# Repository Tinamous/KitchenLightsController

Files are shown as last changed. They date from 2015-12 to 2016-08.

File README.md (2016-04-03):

# KitchenLightsController
IoT Particle Photon powered kitchen lights controller. Switch and dim LED and halogen lights.

Assembly
--------

Mount SMD components.

Solder on JP1, 12V DC power in.
For 2 & 3 min molex headers use sponge to keep connectors in place. Solder single pin, and then reflow that pushing the connector square to the board.
Solder JP35, JP47, JP34, JP48, JP49 - 3 pin molex connectors. Farnell: 9731156
Solder JP201, 202, 203, 301, 302, 303, 401, 402, 403. Optionally solder JP501 or 502. (or both). Fit only as many as you need. Farnell: 9731148

Solder JP43 (terminal block).

Fit C1 (330nF. Farnell: 1902922
Solder headers for Photon. eBay.
F1 Fuse folder. Farnell: 1453528
IC1 7805 or eBay switching version
C4 1000uF 16v. Farnell: 9693610
Connect JP37 if using onboard 5V supply for NeoPixels.
Fit X2 if using USB 5V switch.
Fuse 5A quick blow: Farnell: 1354578

Before powering up:
Check 12V rails for short circuit.
Check 5V rails for short.
Check 3v3 rails for short.

Power up using low current limit on bench PSU (ca. 50m-100A)
Check 5v rail and adjust reg as needed. Expect 3 LEDs to light (12v, 5V and ext. 5V). 14-20mA consumption.

V2.03 Changed:
Moved via under Photon to not mess with silk screen.
Moved OSH logo to near USB A Socket to give it more room and allow the 5V LED to be reverse mounted.
TODO:
Move 5V LED to be reverse mounted
Change 5V usb switched connector to be 0.1" molex not screw terminal.
Correct Channel 4 & Ext. 5V supply screw terminals to be the correct way around (double line on outside of the board).

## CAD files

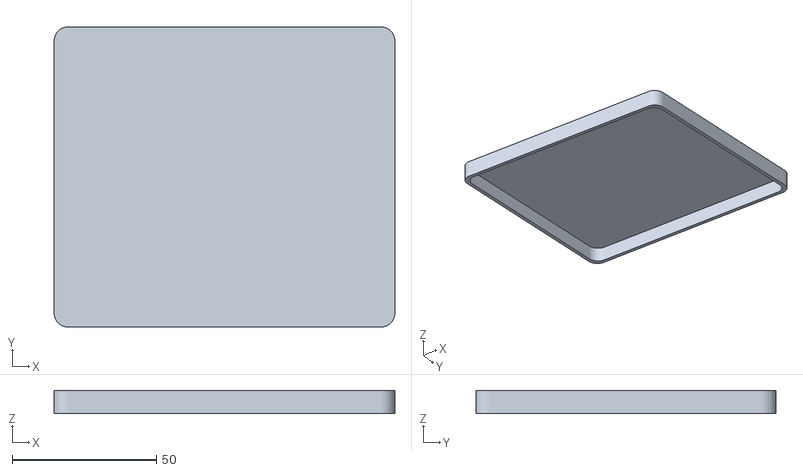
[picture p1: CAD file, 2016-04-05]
Case/LightControllerBoxLid.stl
118.0 x 103.9 x 8.00

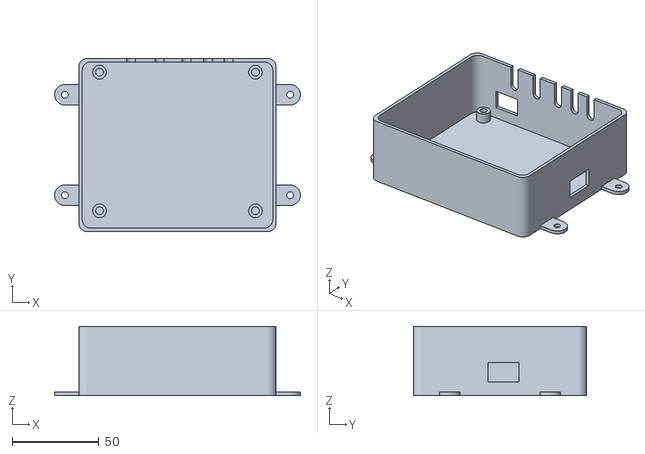
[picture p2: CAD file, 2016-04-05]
Case/LightControllerBox-NoSwitch.stl
142.0 x 99.9 x 40.0

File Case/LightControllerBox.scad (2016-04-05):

boxWidth = 114;
boxDepth = 100;
boxHeight = 40;
//boxHeight = 5;
standOffHeight = 8;
$fn = 20;

// Normal offset is center. Use this
// to push the box left/right/up/down
pcbXOffsetInBox = -0;
pcbYOffsetInBox = 2;

pcbWidth = 100;
pcbHeight = 90;
pcbMountOffset = 5; // m55 in from top/bottom for the PCB mounting hole

pcbOffsetX = ((boxWidth - pcbWidth) /2) + pcbXOffsetInBox; // 7.5mm
pcbOffsetY = ((boxDepth - pcbHeight) /2) + pcbYOffsetInBox;  // 15mm

switchDiameter = 17.5; 
switchX = (boxWidth/4) *3;
switchY = boxHeight - 15;

// Mounting. Tabs/Holes?
includeTabs = true;
includeHoles = false;
includeMountingPosts = false;

// Which part to build?
showBox = false;
showLid = true;
includeSwitchHole = false;

// Debugging
showPcb = false;
showSwitch = false;


// -----------------------------------------
// -----------------------------------------
module GenericBase(xDistance, yDistance, zHeight) {
	// roundedBox([xDistance, yDistance, zHeight], 2, true);

	// Create a rectangluar base to work from that
	// is xDistance by yDistance and zHeight height.

	// This is effectivly a cube with rounded corners

	// extend the base out by 3.5 from holes by using minkowski
	// which gives rounded corners to the board in the process
	// matching the Gadgeteer design
	
	$fn=30;
	radius = 5; //bezelSize;
	translate([radius,radius,0]) {
		minkowski()
		{
			// 3D Minkowski sum all dimensions will be the sum of the two object's dimensions
			cube([xDistance-(radius*2), yDistance-(radius*2), zHeight /2]);
			cylinder(r=radius,h=zHeight/2);
		}
	}
}

module OuterBox() {
    difference() {
        union() {
            GenericBase(boxWidth,boxDepth,boxHeight);
        }
        union() {
            translate([2,2,2]) {
                GenericBase(boxWidth - 4,boxDepth-4,boxHeight);
            }
            
            //translate([boxWidth /2,boxDepth/2,0]) {
            /*
            // Through hold
            translate([boxWidth /2,boxDepth-15,0]) {
                cylinder(d=15, h=3);
            }
            */
            
            // Drill out the mounting holes
            if (includeHoles) {
                MountingHoles();
            }
            
            if (includeSwitchHole) {
                SwitchHole();
            }
            
            cableExitHoles();
            
            usbConnectorHole();
            
            powerConnectorHole();
        }
    }
}

module cableExitHole(width) {
    #cube([width, 10,20]);
    translate([ (width/2), 10, 0]) {
        rotate([90,0,0]) {
            #cylinder(d=width, h=10);
        }
    }
}

module powerConnectorHole() {   
    
    translate([pcbOffsetX + 9.5, boxDepth-4,  standOffHeight+1]) {    
        #cube([16,7, 11]);
    }
}

// This may need supports.
module usbConnectorHole() {
    translate([boxWidth-4, pcbOffsetY + 36,  standOffHeight]) {    
        #cube([8,18, 8 + 3]);
    }
}

// Cut out holes in the wall for the light cables
// to exit.
module cableExitHoles() {
    
    translate([pcbOffsetX, boxDepth -4,  boxHeight-12]) {    
        // Channel 1
        translate([20.5, 0, 0]) {
            cableExitHole(5.2);
        }
        
        // Channel 2
        translate([37, 0, 0]) {
            cableExitHole(5.2);
        }
        
        // Channel 3
        translate([52.7, 0, 0]) {
            cableExitHole(5.2);
        }
        
        // Channel 4
        translate([65, 0, 0]) {
            cableExitHole(5.2);
        }
        
        // NeoPixels
        translate([76.7, 0, 0]) {
            cableExitHole(5.2);
        }
    }   
}

module PcbMounts() {
    
    // Mount holes @5,5 in corners of PCV        
    PcbMount(pcbOffsetX + pcbMountOffset, pcbOffsetY + pcbMountOffset);
    PcbMount(pcbOffsetX + pcbMountOffset, pcbOffsetY + pcbHeight - pcbMountOffset);
    PcbMount(pcbOffsetX + pcbWidth - pcbMountOffset, pcbOffsetY + pcbMountOffset);
    PcbMount(pcbOffsetX + pcbWidth - pcbMountOffset, pcbOffsetY + pcbHeight - pcbMountOffset);
}

module PcbMount(x,y) {
mountSize = 8;
mountHoleSize = 4.5;
    
    translate([x,y,0]) {
        // Outer pad + inner hole (Not all the way through!)
        difference() {
            union() {
                cylinder(d=mountSize, h=standOffHeight);
            }
            union() {
                translate([0,0,2]) {
                    #cylinder(d=mountHoleSize, h=standOffHeight-2);
                }
            }
        }
    }
}

module LidPosts() {
    LidPost(0,0);
    LidPost(boxWidth-(2*5),0);
    LidPost(0,boxDepth-(2*5));
    LidPost(boxWidth-(2*5),boxDepth-(2*5));
}

module LidPost(x,y) {
    mountSize = 7;
    mountHoleSize = 3; //M3 hole
    lidDepth = 0;

    translate([x + 5,y + 5,0]) {
        // Outer pad + inner hole (Not all the way through!)
        difference() {
            union() {
                cylinder(d=mountSize, h=boxHeight - lidDepth);
            }
            union() {
                // 10mm hole from top only
                translate([0,0,boxHeight - lidDepth - 10]) {
                    #cylinder(d=mountHoleSize, h=10);
                }
            }
        }
    }
}

module MountingHoles() {
    offsetFromCorner = 30;
    MountingHole(offsetFromCorner,offsetFromCorner);
    MountingHole(boxWidth-offsetFromCorner,offsetFromCorner);
    MountingHole(offsetFromCorner,boxDepth-offsetFromCorner);
    MountingHole(boxWidth-offsetFromCorner,boxDepth - offsetFromCorner);
}

module MountingHole(x,y) {
    translate([x,y,0]) {
        #cylinder(d=4, h=2);
    }
}

module MountingTabs() {
    
    tabOffset = 15;
    tabWidth = 12;
    tabLength = 8;
    
    MountingTab(0, tabOffset, tabWidth, tabLength);
    MountingTab(0, boxDepth - tabOffset - tabWidth, tabWidth, tabLength);
    
    translate([boxWidth,boxDepth,0]) {
        rotate([0,0,180]) {
            MountingTab(0,15, tabWidth, tabLength);
            MountingTab(0, boxDepth - tabOffset - tabWidth, tabWidth, tabLength);
        }
    }
}

module MountingTab(x,y, tabWidth, tabLength, tabThickness = 2) {
    
    translate([x - tabLength,y ,0]) {
        
        
        difference() {
            union() {
                cube([tabLength,tabWidth,tabThickness]);
                
                translate([0,(tabWidth/2) ,0]) {
                    cylinder(d=tabWidth, h=tabThickness);
                }
            }
            union() {
                // Hole for screw
                translate([0,(tabWidth/2) ,0]) {
                    cylinder(d=4, h=4);
                }
            }
        }
    }
}

module SwitchHole() {
        
    rotate([90,0,0]) {
        translate([switchX,switchY,-3]) {
            #cylinder(d=switchDiameter, h=5);
        }
    }
}
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

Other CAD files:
Case/LightControllerBox.stl

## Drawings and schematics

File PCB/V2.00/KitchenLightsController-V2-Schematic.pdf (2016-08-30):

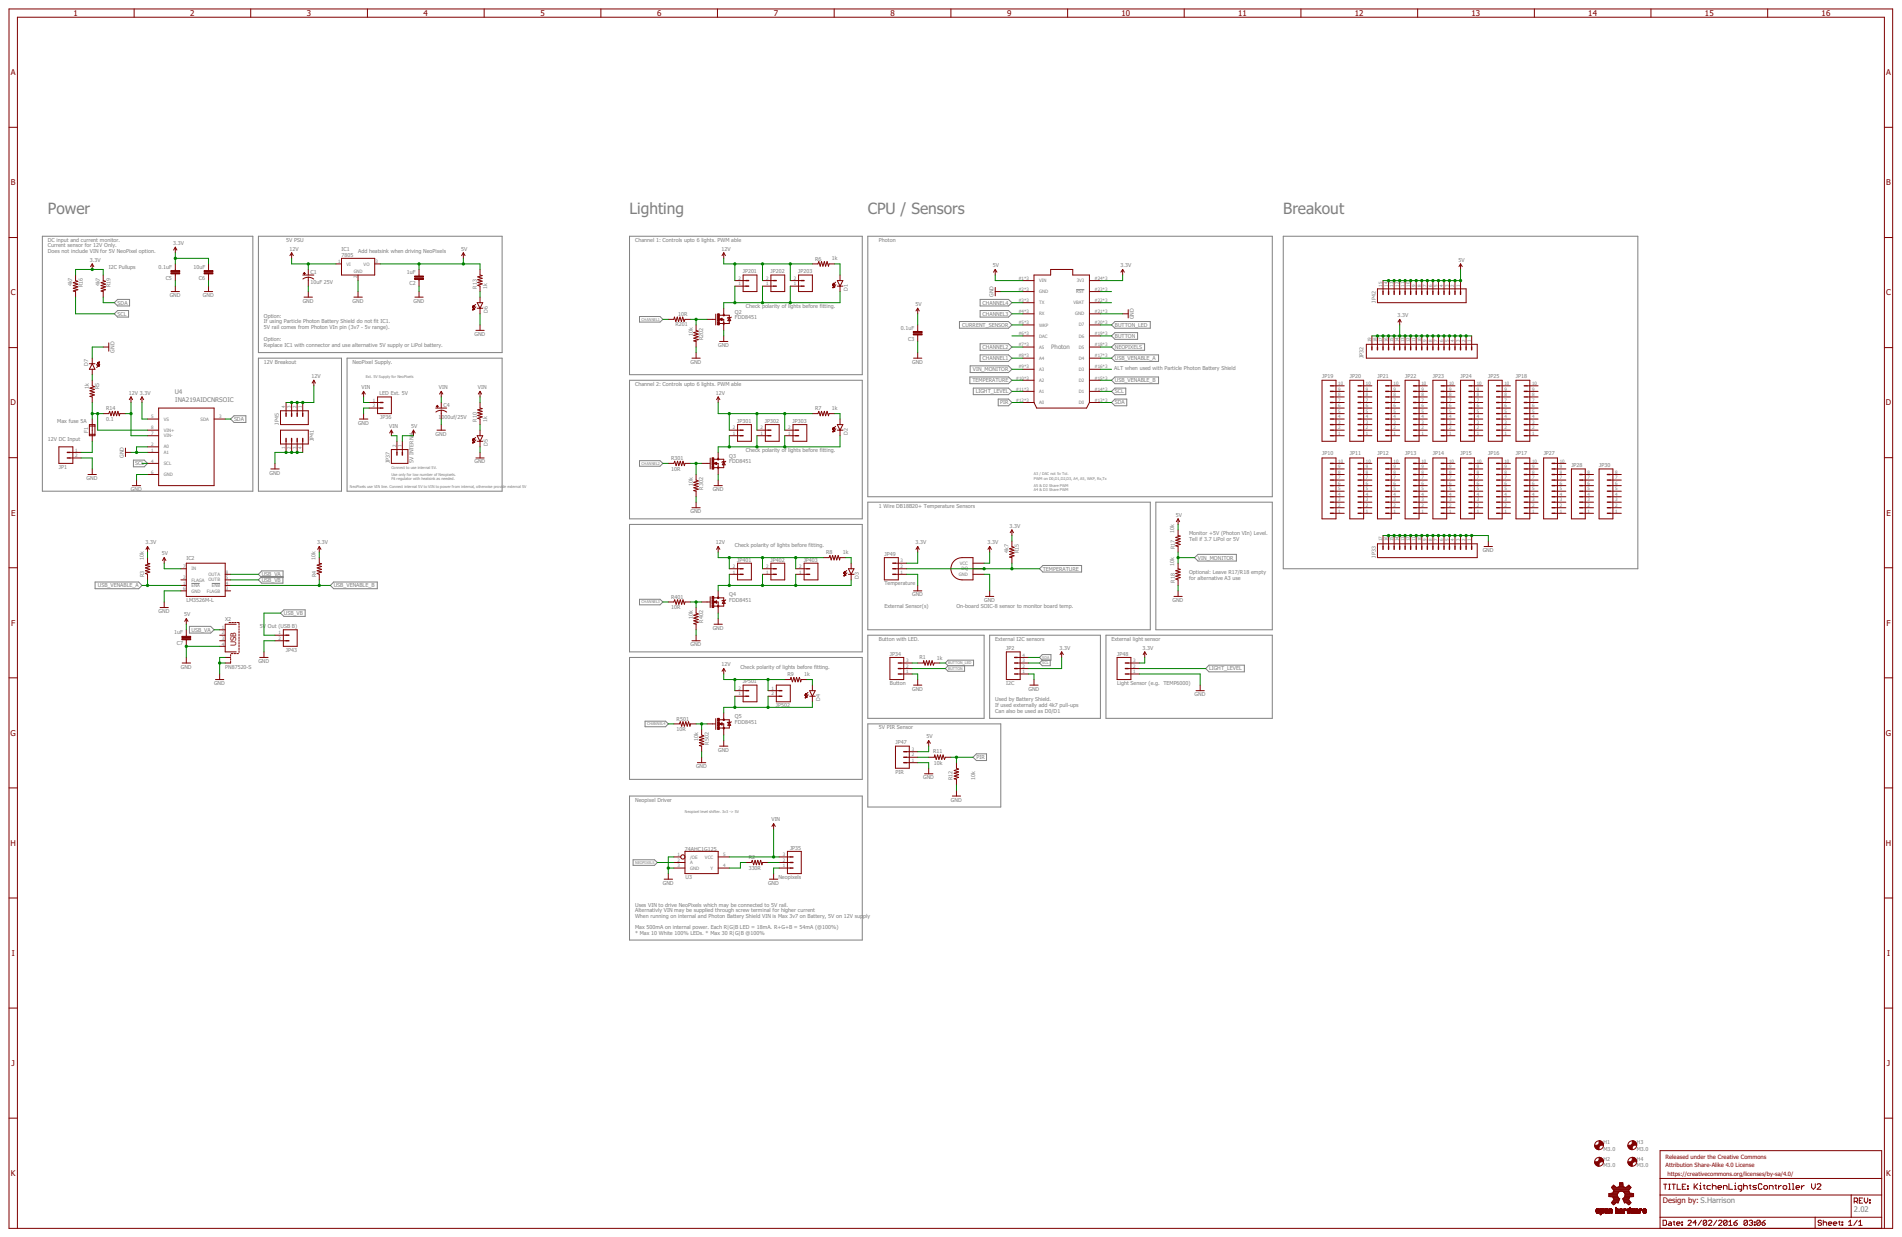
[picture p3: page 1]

DC input and current monitor.
Add heatsink when driving NeoPixels Current sensor for 12V Only. Does not include VIN for 5V NeoPixel option.

Channel 1: Controls upto 6 lights. PWM able

Option: If using Particle Photon Battery Shield do not fit IC1. 5V rail comes from Photon VIn pin (3v7 - 5v range). Option: Replace IC1 with connector and use alternative 5V supply or LiPol battery.

Check polarity of lights before fitting.
FDD8451

Ext. 5V Supply for NeoPixels

ALT when used with Particle Photon Battery Shield

Channel 2: Controls upto 6 lights. PWM able

12V DC Input Max fuse 5A

Connect to use internal 5V. Use only for low number of Neopixels. Fit regulator with heatsink as needed.

A3 / DAC not 5v Tol. PWM on D0,D1,D2,D3, A4, A5, WKP, Rx,Tx A5 & D2 Share PWM

NeoPixels use VIN line. Connect internal 5V to VIN to power from internal, otherwise provide external 5V

Monitor +5V (Photon VIn) Level. Tell if 3.7 LiPol or 5V Optional: Leave R17/R18 empty

Used by Battery Shield. If used externally add 4k7 pull-ups Can also be used as D0/D1

Uses VIN to drive NeoPixels which may be connected to 5V rail. Alternativly VIN may be supplied through screw terminal for higher current When running on internal and Photon Battery Shield VIN is Max 3v7 on Battery, 5V on 12V supply Max 500mA on internal power. Each R|G|B LED = 18mA. R+G+B = 54mA (@100%) * Max 10 White 100% LEDs. * Max 30 R|G|B @100%

Released under the Creative Commons Attribution Share-Alike 4.0 License https://creativecommons.org/licenses/by-sa/4.0/ Design by:

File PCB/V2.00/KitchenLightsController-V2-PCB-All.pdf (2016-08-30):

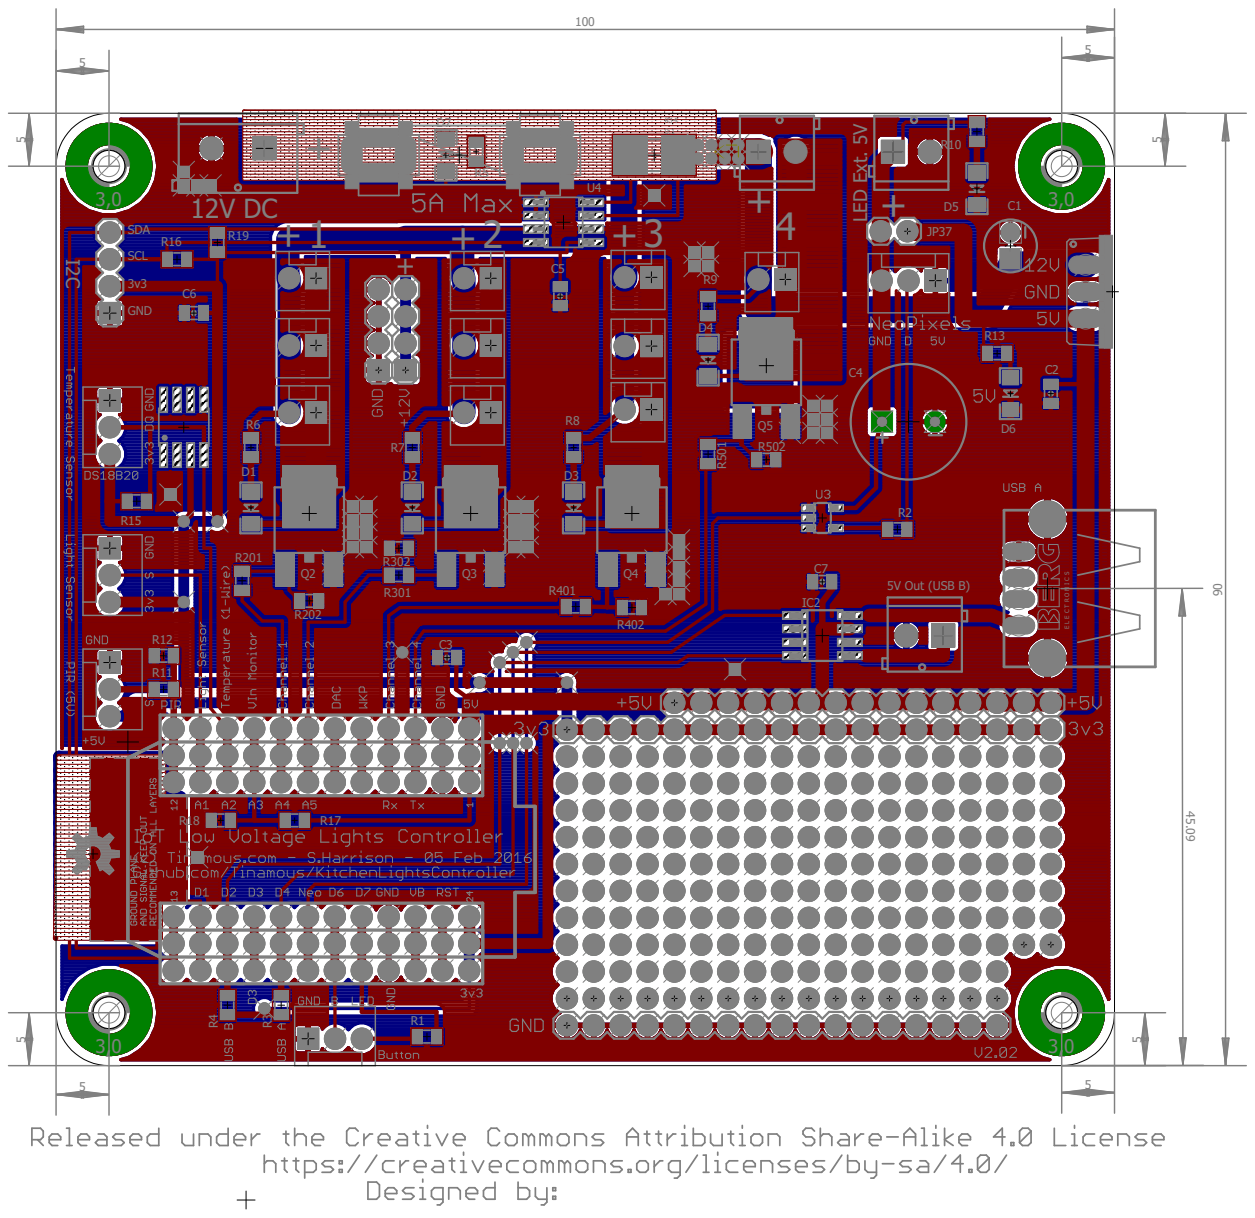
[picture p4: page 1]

GND

5V Out (USB B)

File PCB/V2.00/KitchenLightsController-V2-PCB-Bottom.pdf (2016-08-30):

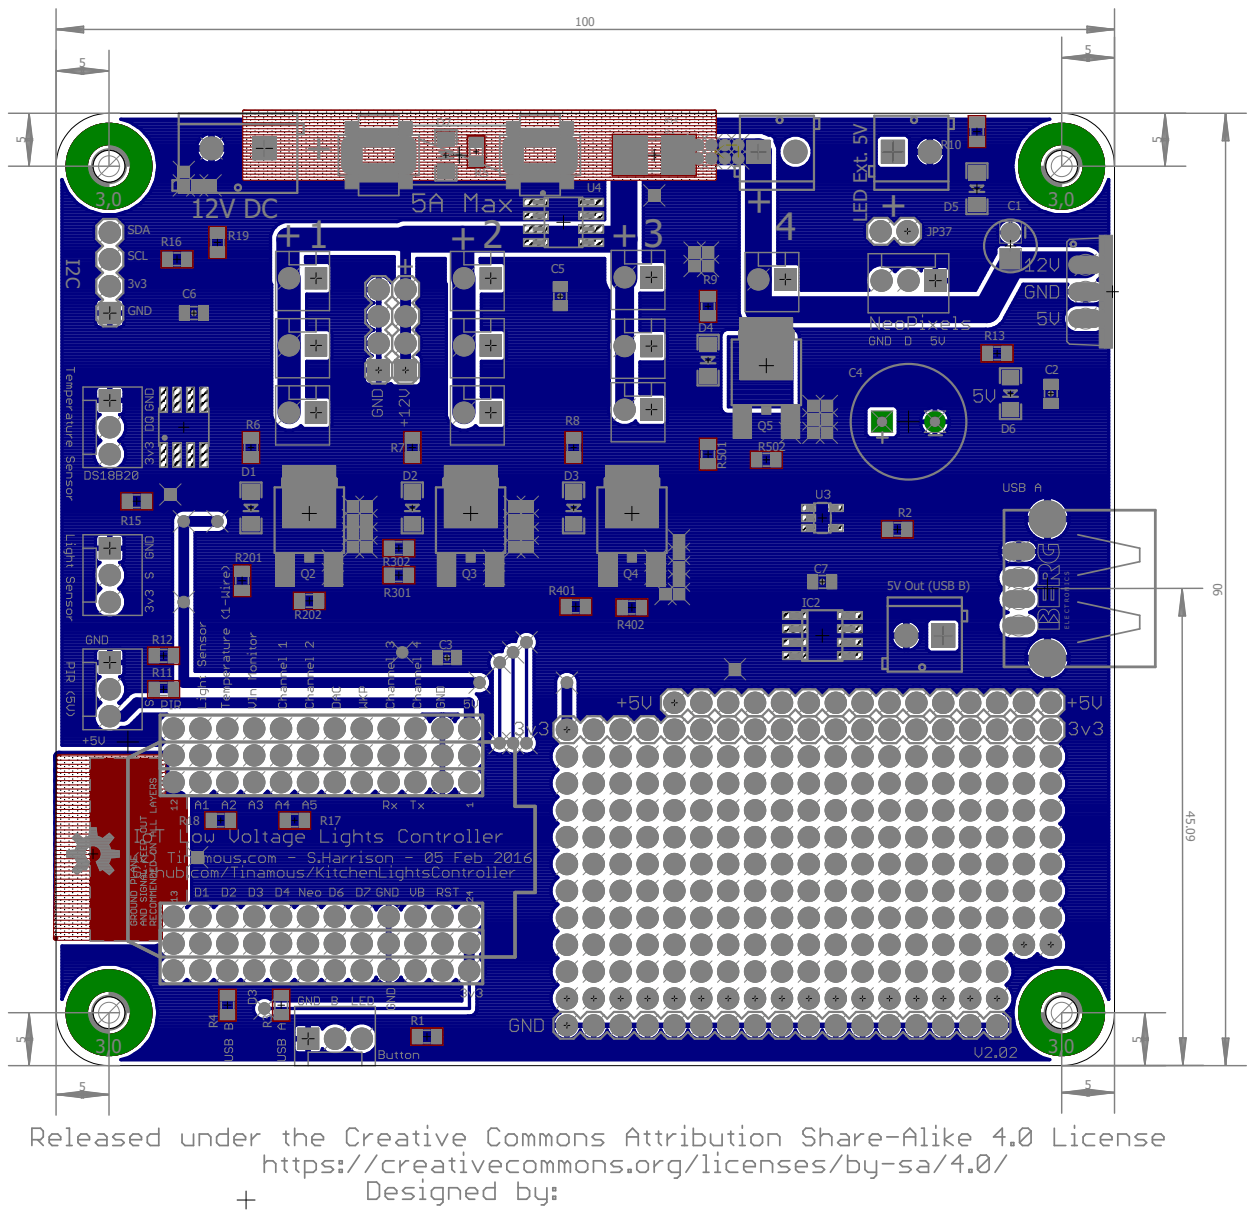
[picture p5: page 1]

5V Out (USB B)

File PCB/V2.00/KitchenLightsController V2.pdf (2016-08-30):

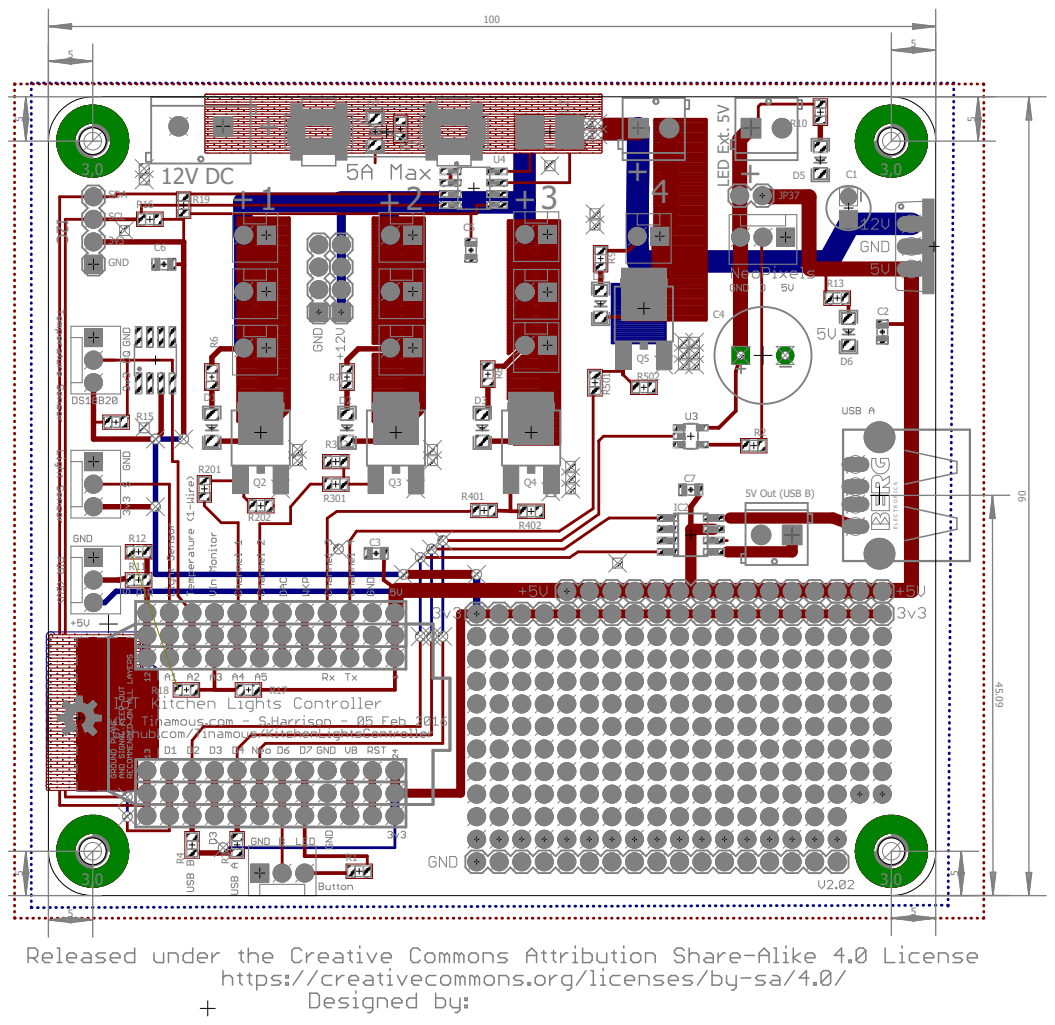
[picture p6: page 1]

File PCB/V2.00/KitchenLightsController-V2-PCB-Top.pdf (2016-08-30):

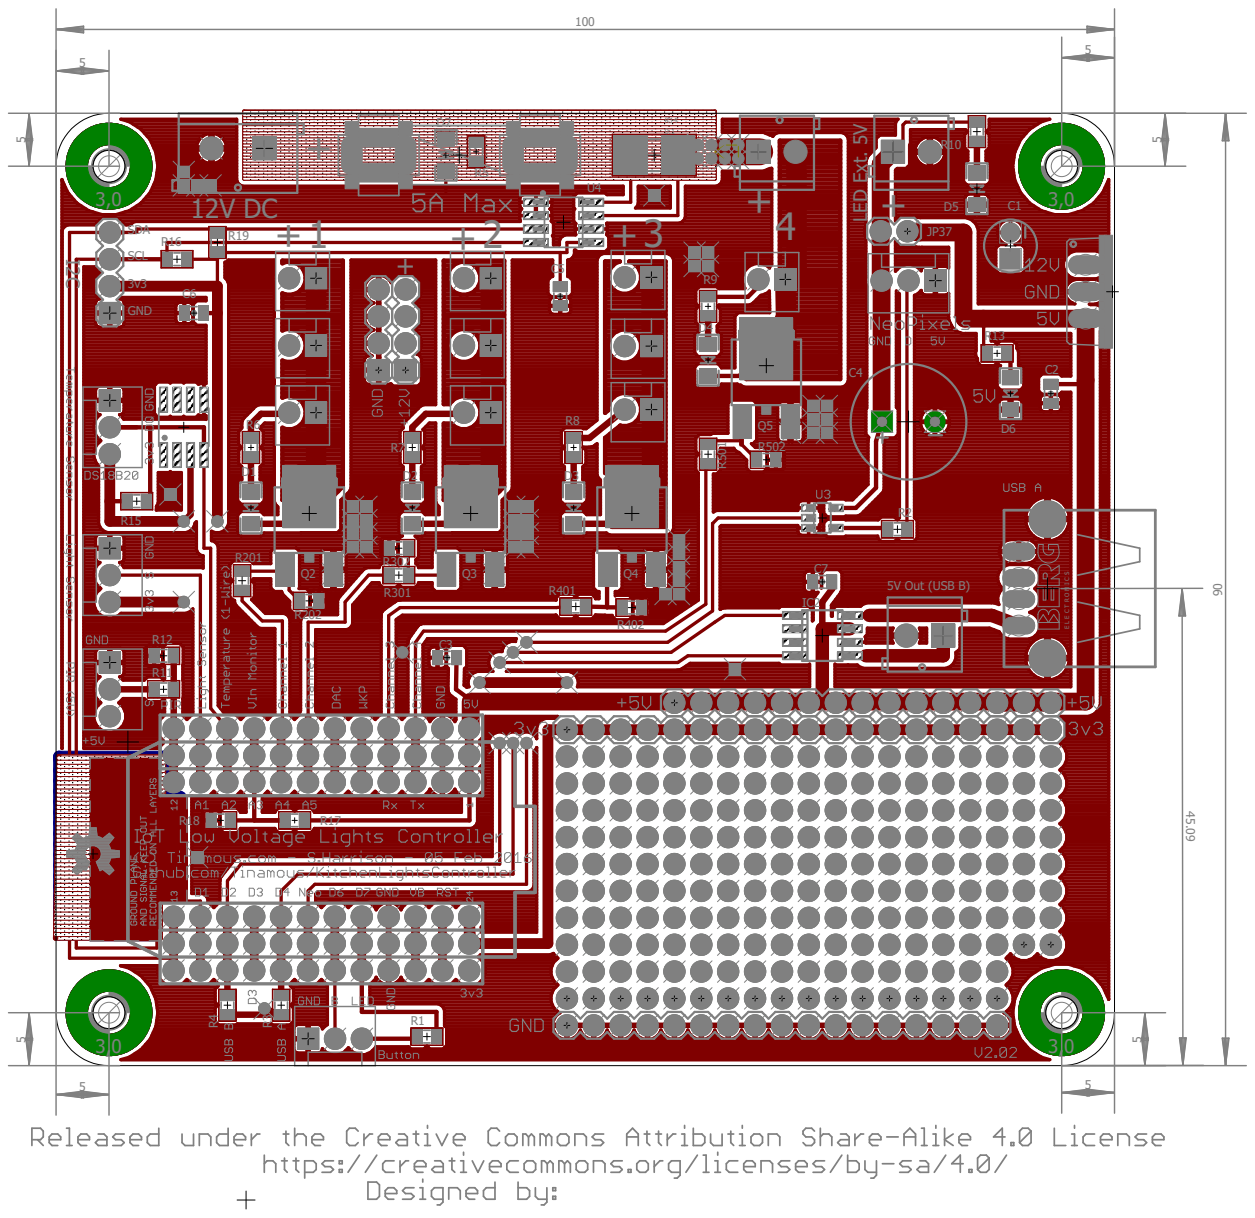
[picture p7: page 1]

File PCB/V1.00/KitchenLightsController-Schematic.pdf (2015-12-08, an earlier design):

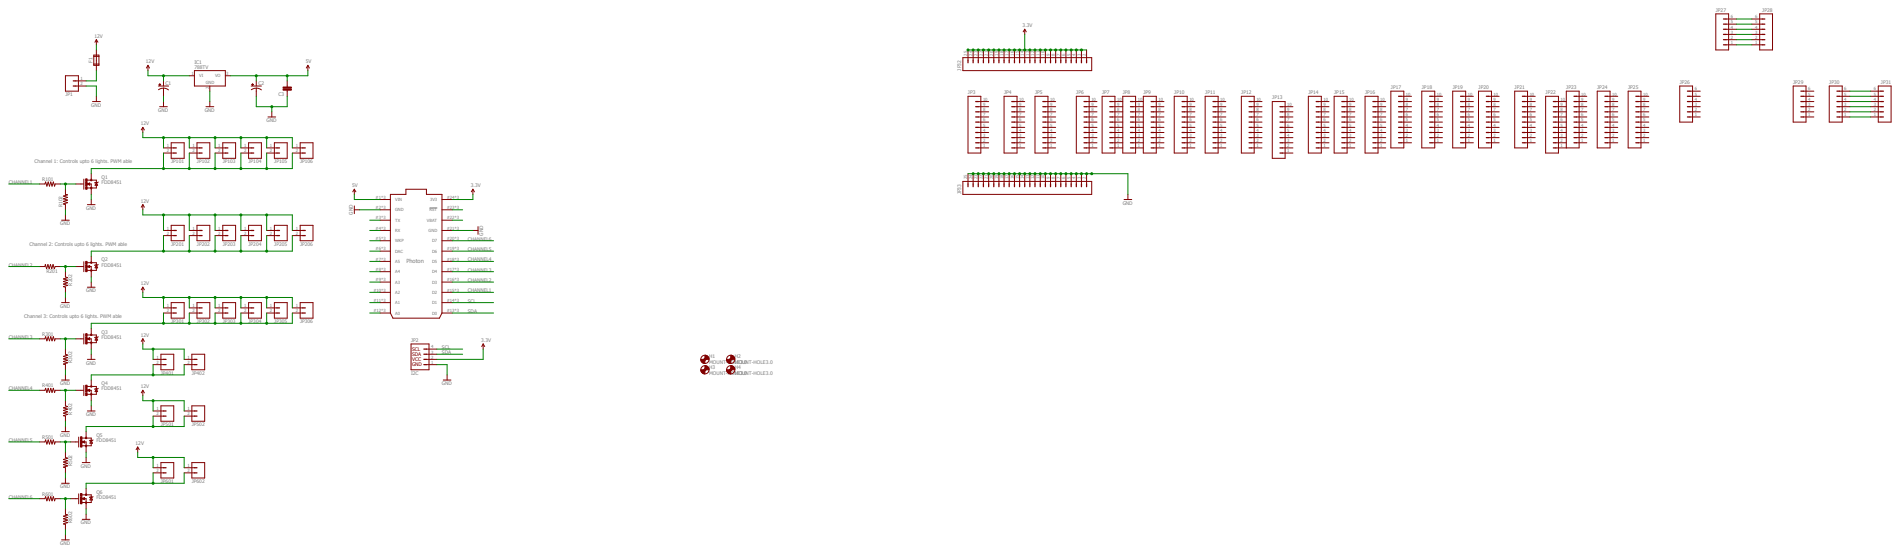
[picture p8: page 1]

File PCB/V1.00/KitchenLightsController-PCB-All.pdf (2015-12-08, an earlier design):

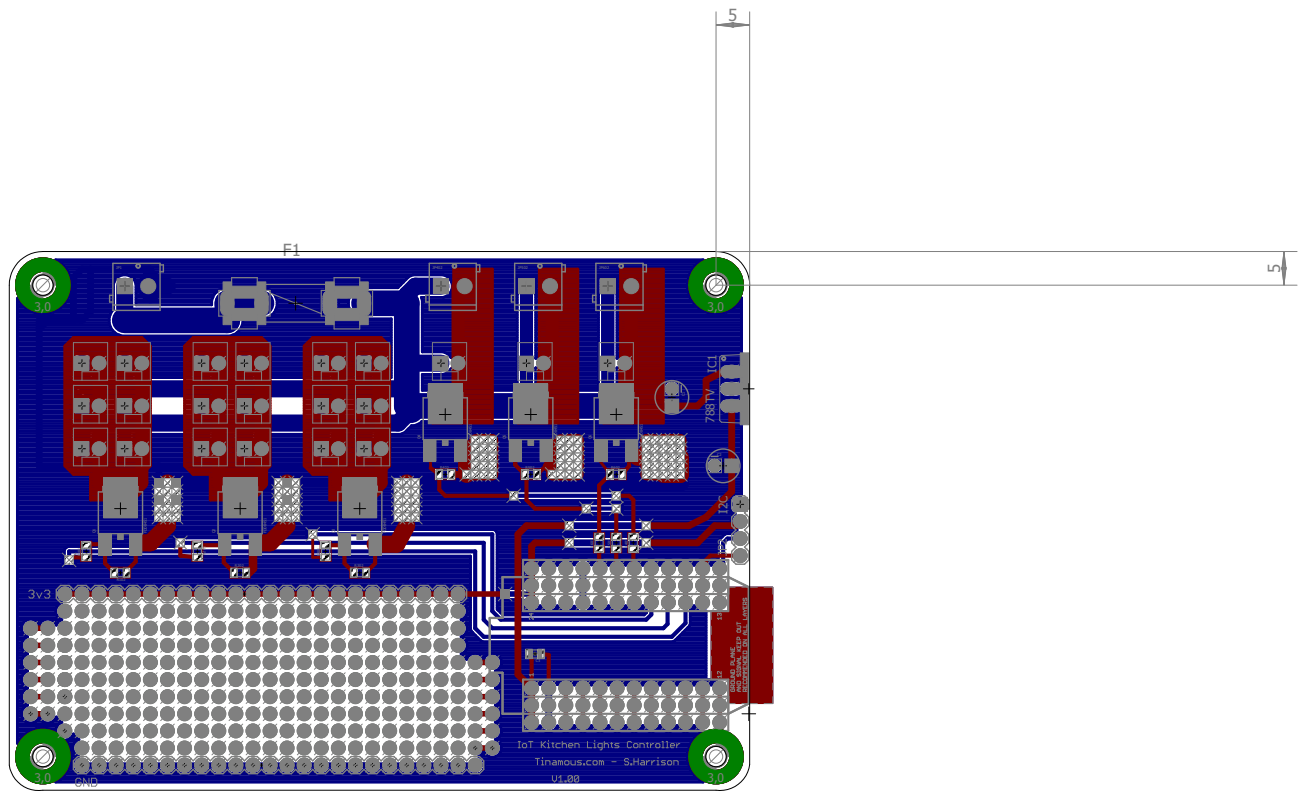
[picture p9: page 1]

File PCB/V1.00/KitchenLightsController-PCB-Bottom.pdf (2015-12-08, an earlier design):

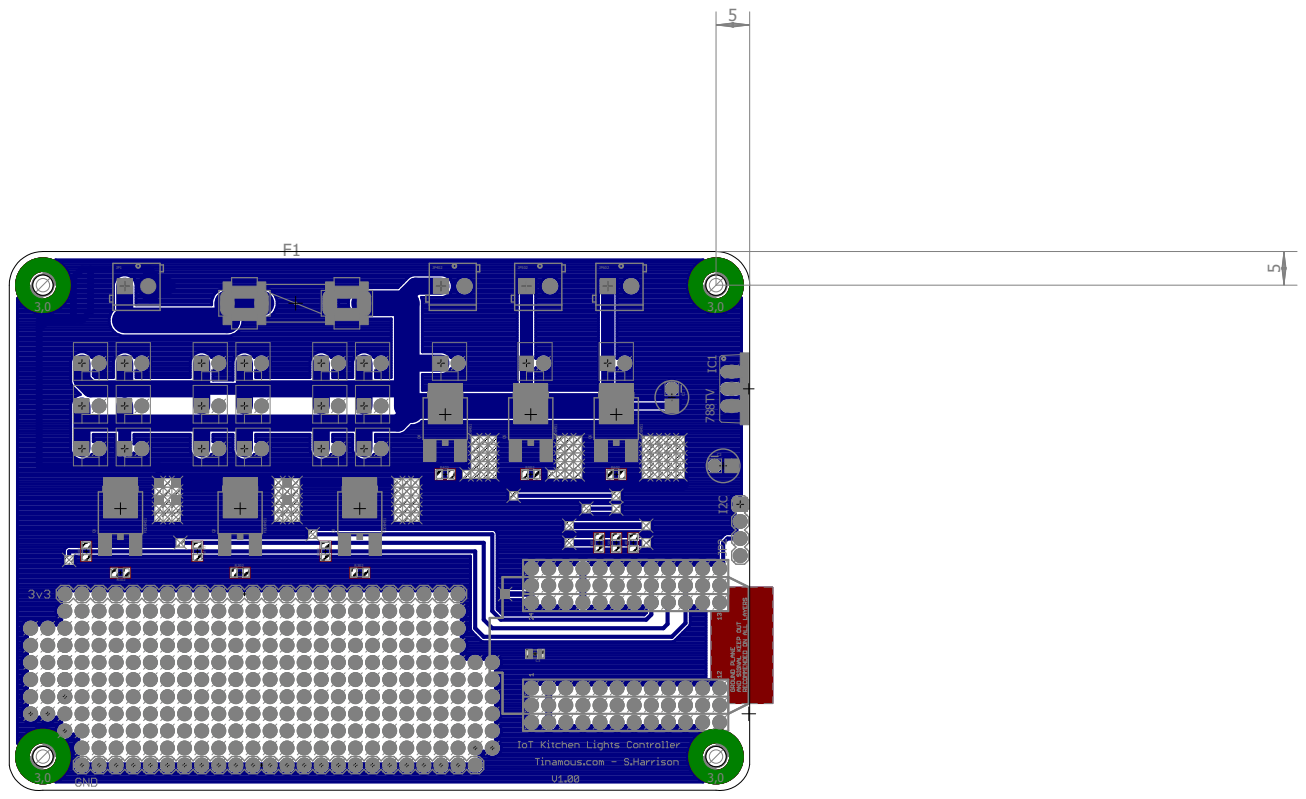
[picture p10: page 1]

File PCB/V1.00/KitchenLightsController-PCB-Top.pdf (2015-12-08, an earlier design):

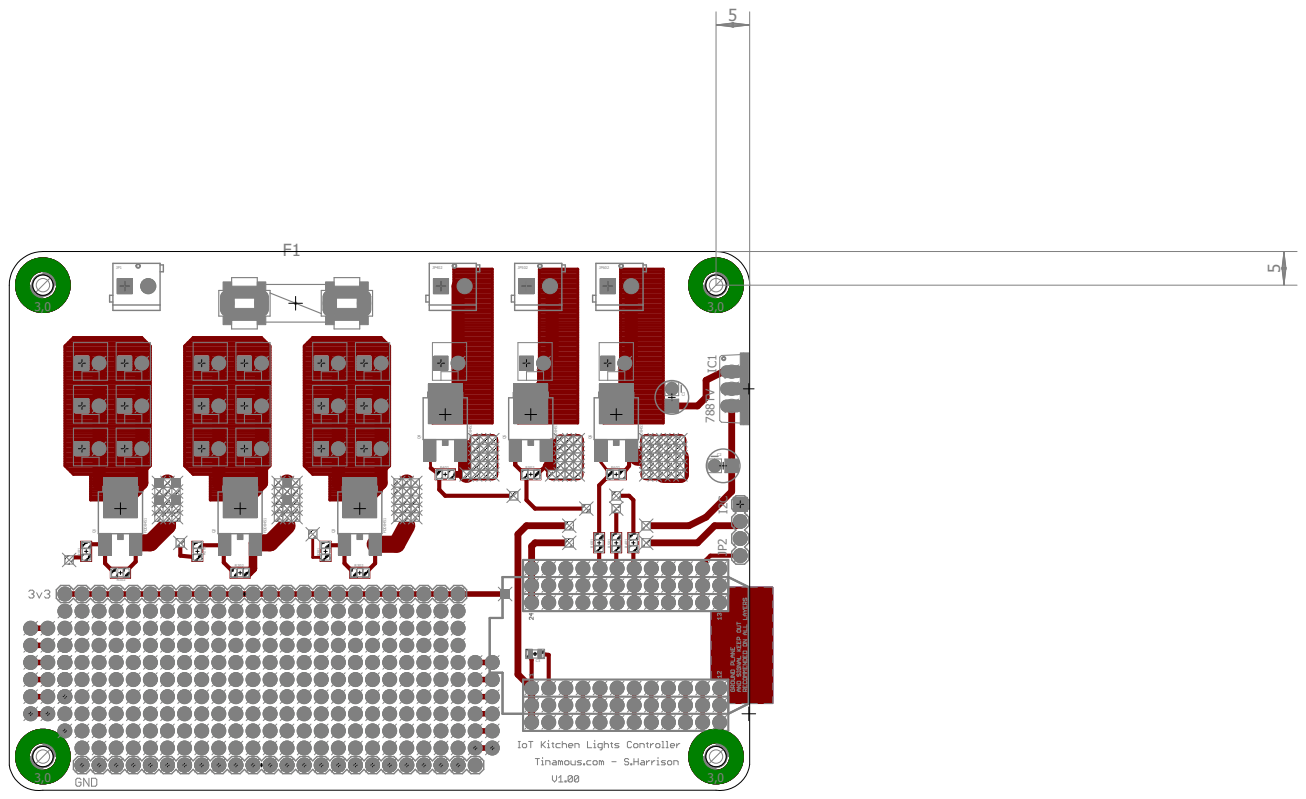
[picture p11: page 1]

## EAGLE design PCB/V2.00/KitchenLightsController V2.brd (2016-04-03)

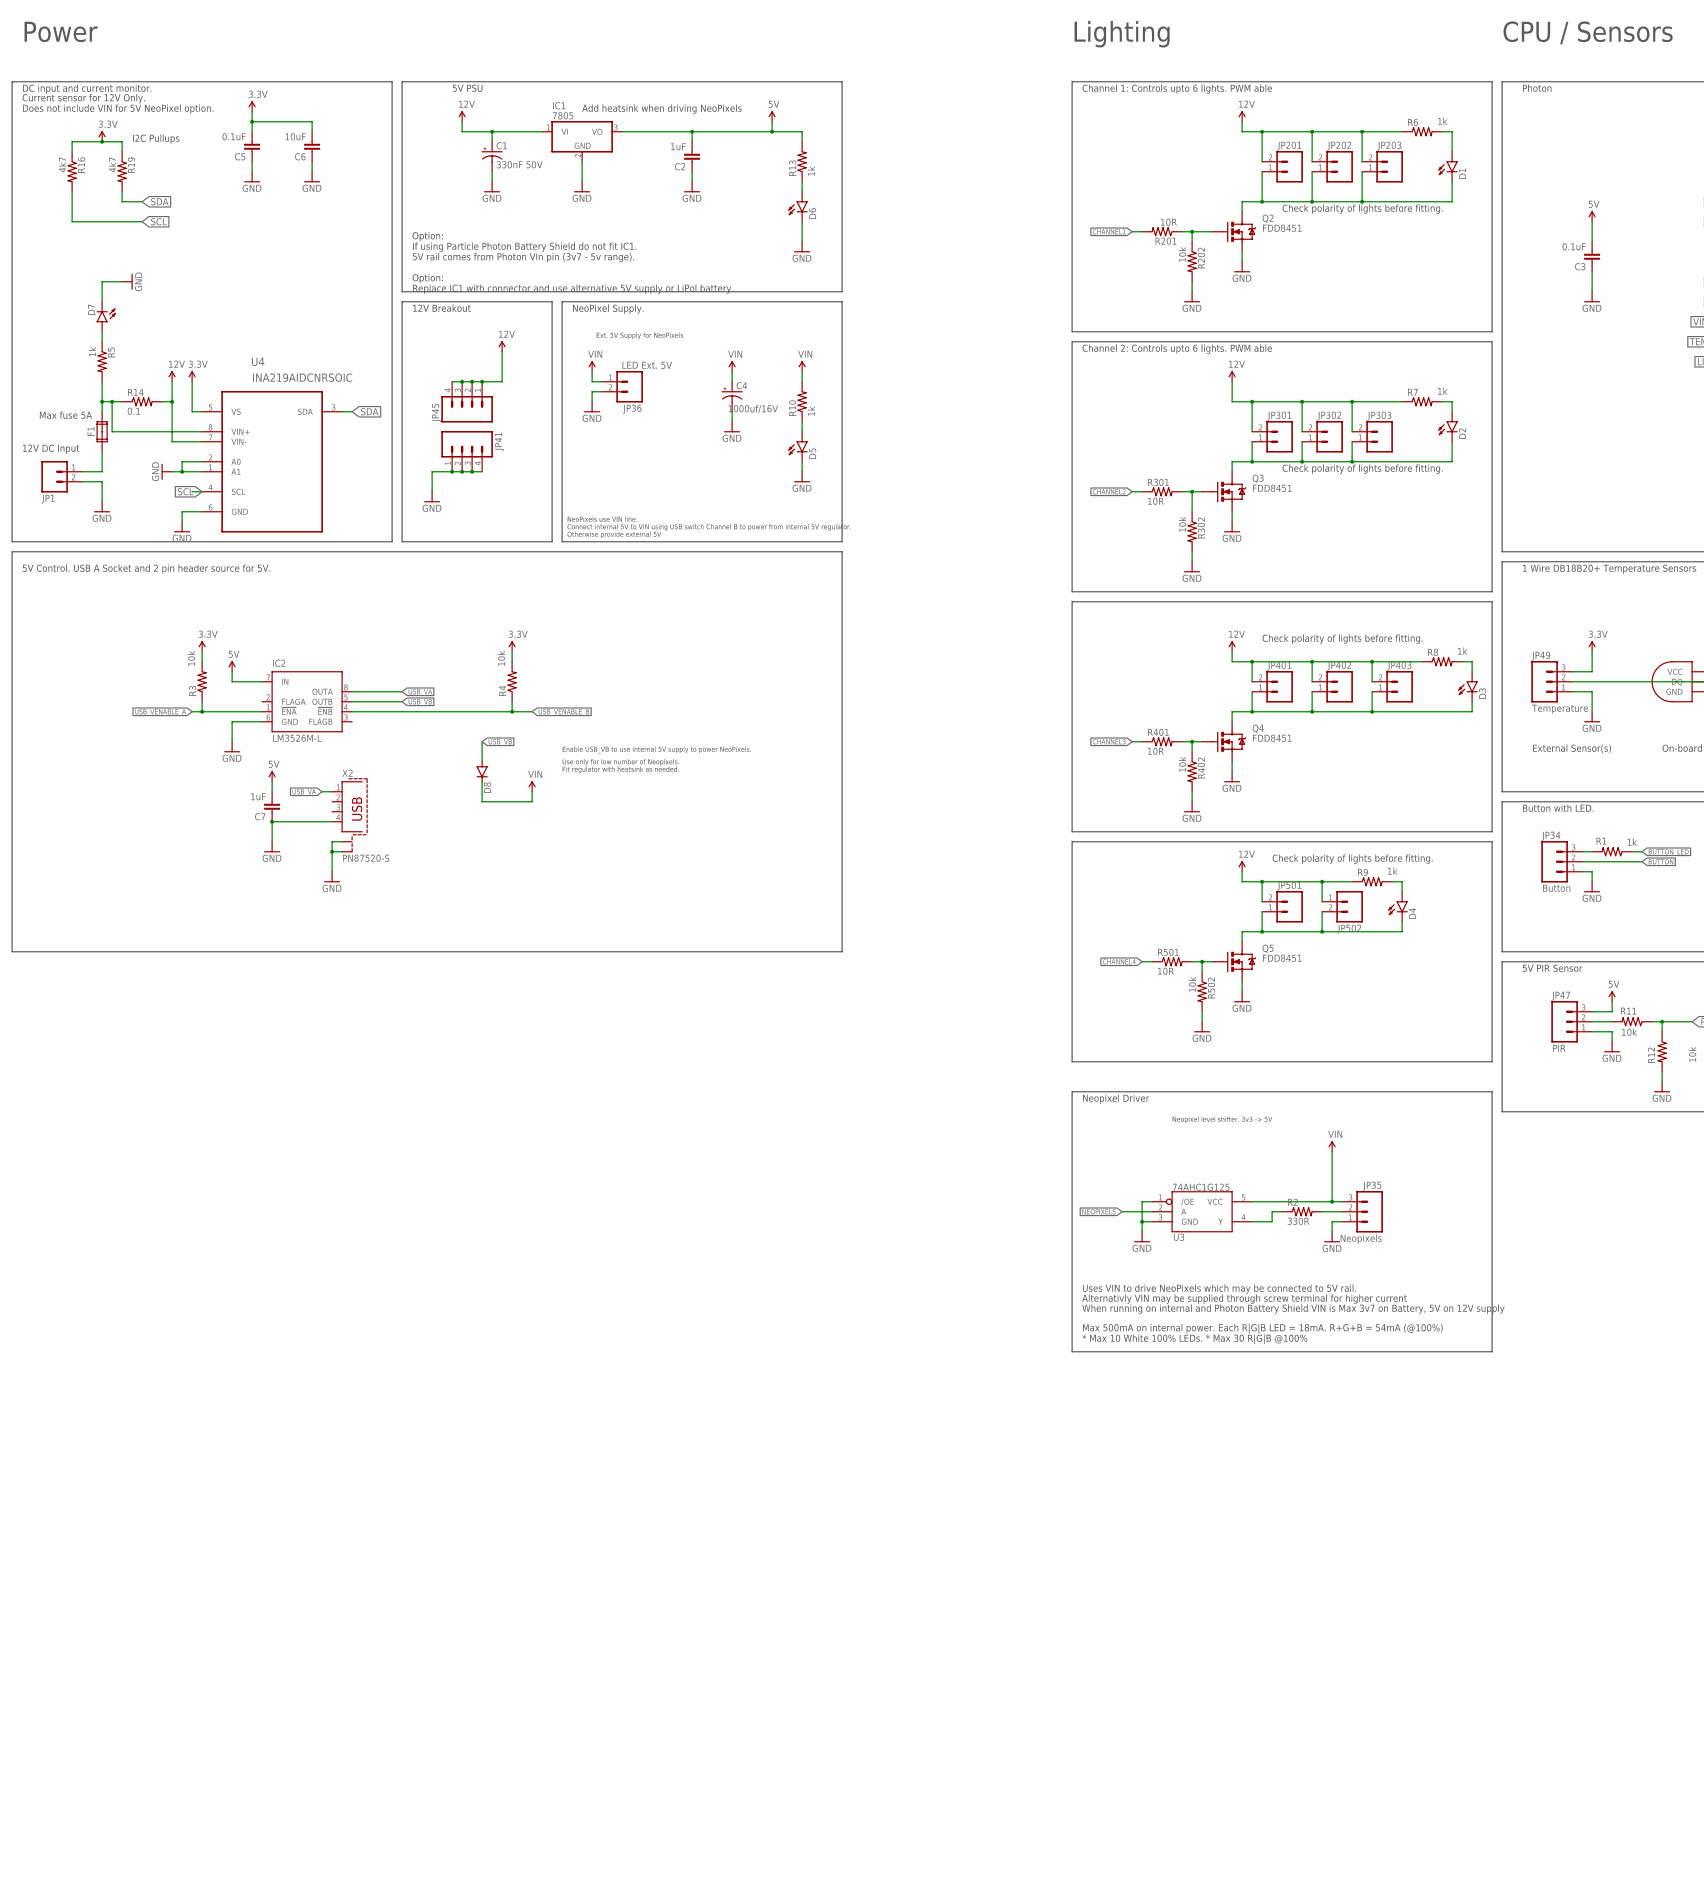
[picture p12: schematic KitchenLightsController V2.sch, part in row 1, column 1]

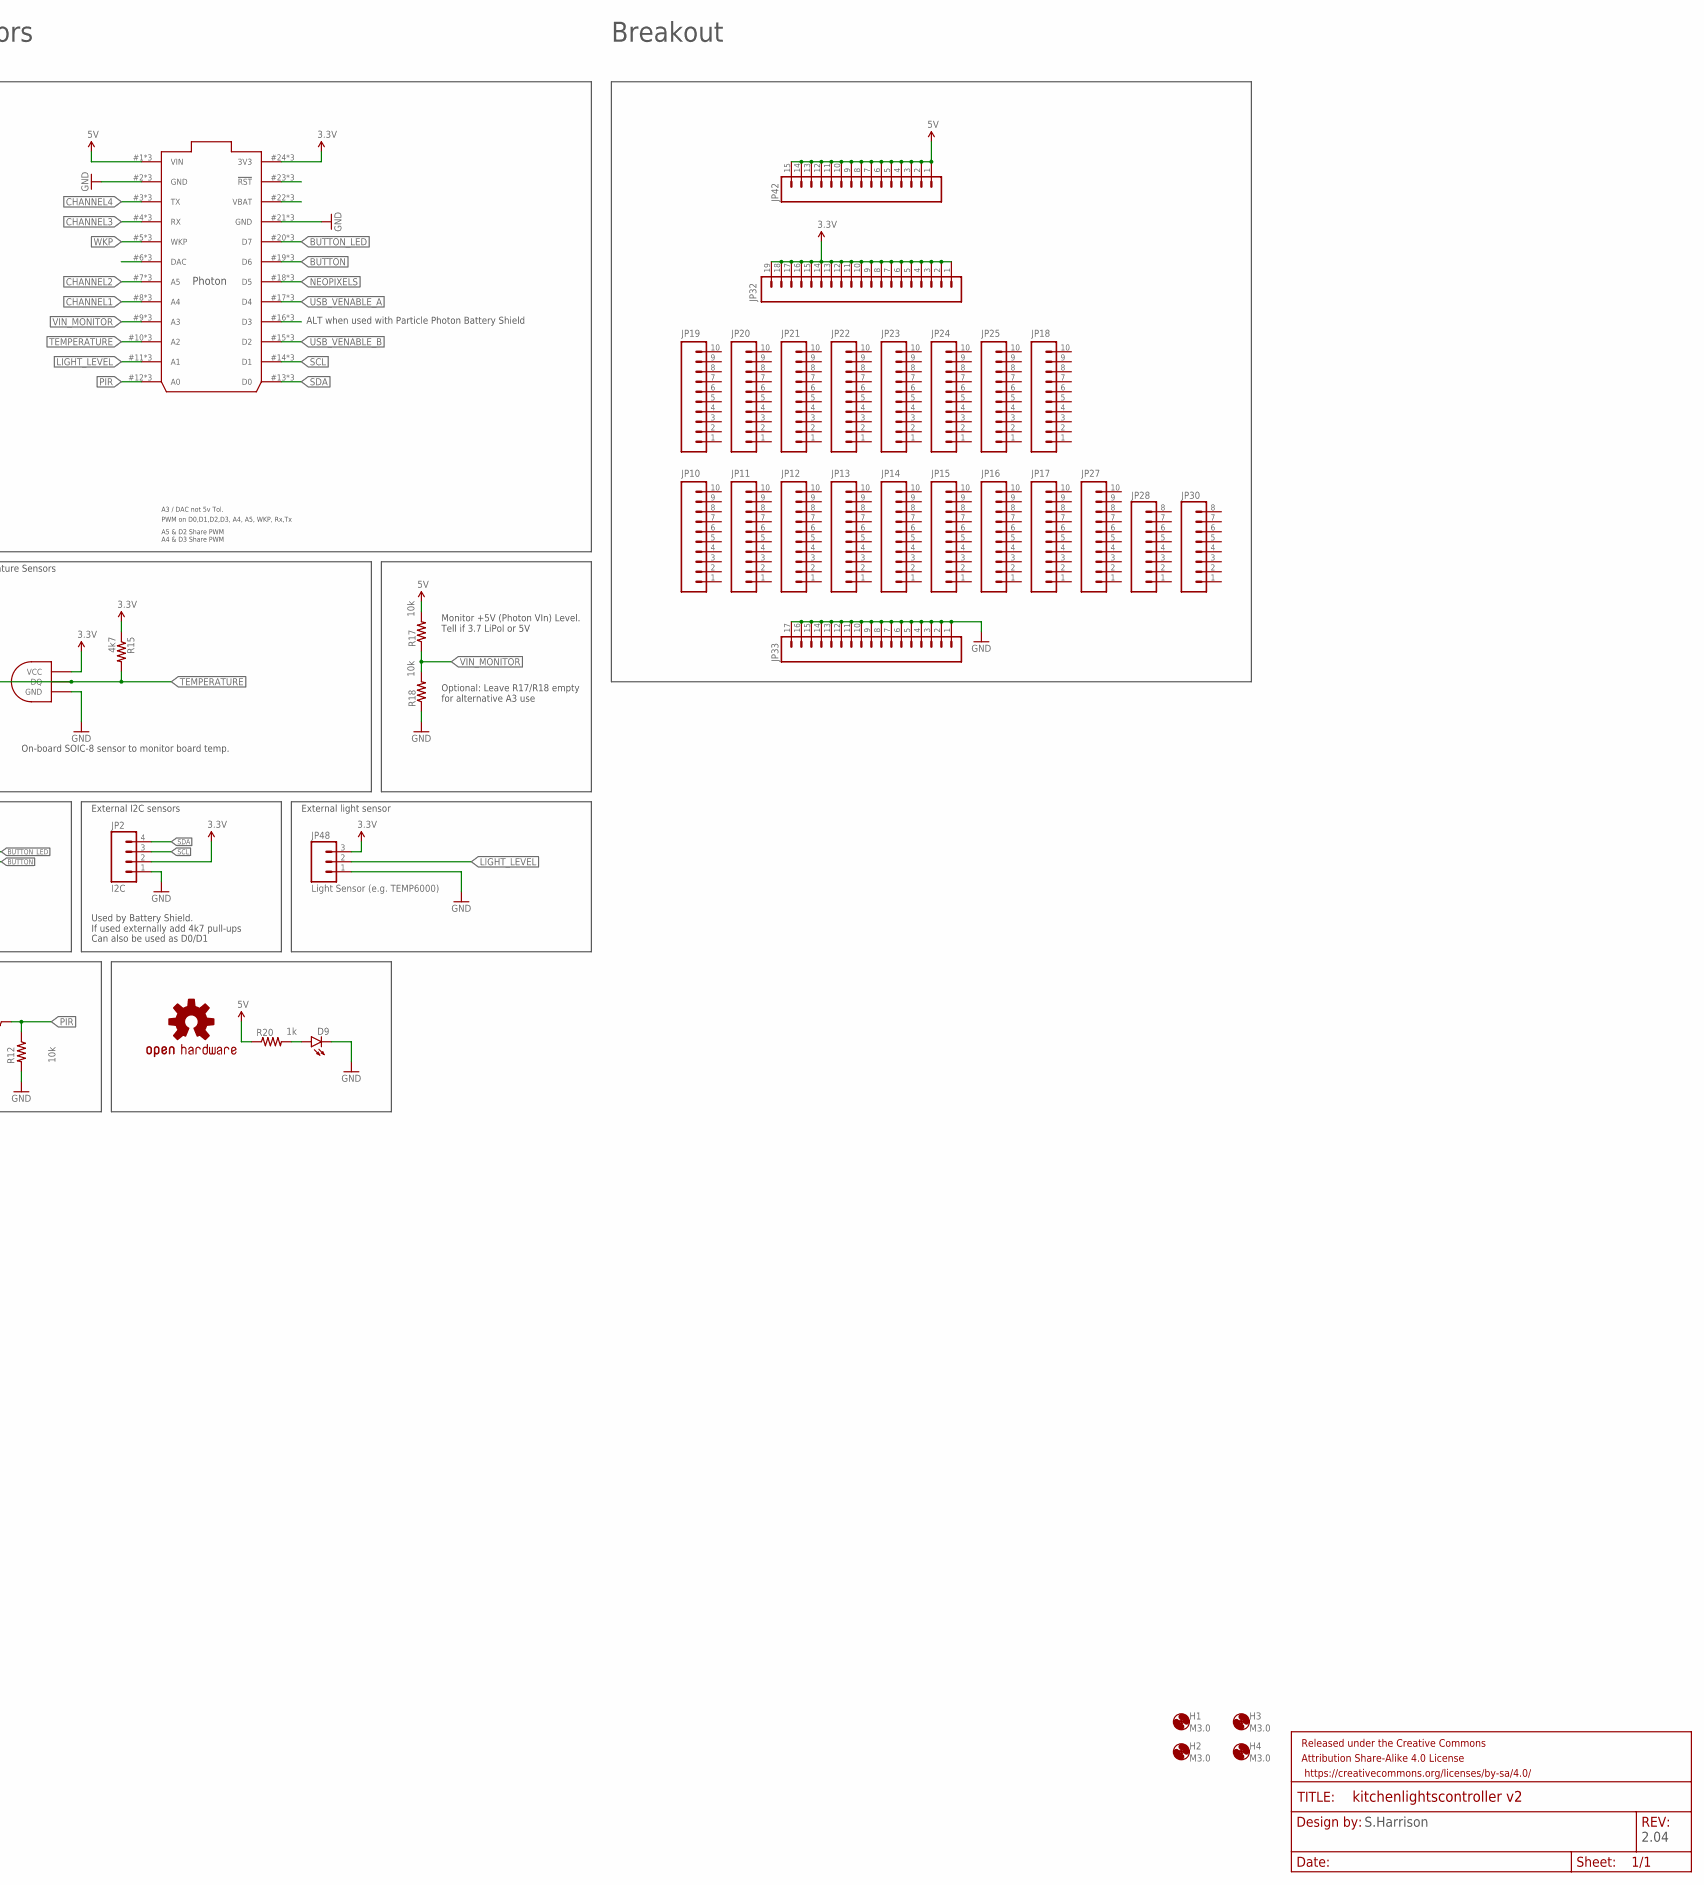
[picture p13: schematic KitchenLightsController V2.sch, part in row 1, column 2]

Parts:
C1: 330nF 50V; CPOL-RADIAL-10UF-25V; FARNELL 1902922
C2, C7: 1uF; 0805-CAP
C3, C5: 0.1uF; 0805-CAP
C4: 1000uf/16V; CPOL-RADIAL-1000UF-25V-KIT; FARNELL 9693610
C6: 10uF; 0805-CAP
D1, D2, D3, D4, D5, D6, D7: GREEN; LED-1206
D8: DIODESMA-KIT; SMA-DIODE-KIT
D9: LED1206-BOTTOM; LED-1206-BOTTOM
F1: FUSE2P; FUSE1; FARNELL 1453528
FRAME1: FRAME-LETTER; CREATIVE_COMMONS
H1, H2, H3, H4: M3.0; 3,0
IC1: 7805; TO220V
IC2: LM3526M-L; SO08
JP1: M025MM; SCREWTERMINAL-5MM-2; FARNELL 2008197
JP2: I2C; 1X04
JP10, JP11, JP12, JP13, JP14, JP15, JP16, JP17, JP18, JP19, JP20, JP21, JP22, JP23, JP24, JP25, JP27: M10NO_SILK_PTH_FEMALE; 1X10_NO_SILK
JP28, JP30: M08NO_SILK_FEMALE_PTH; 1X08_NO_SILK
JP32: M191X19; 1X19
JP33: M17; 1X17
JP34: Button; MOLEX-1X3; FARNELL 9731156
JP35: Neopixels; MOLEX-1X3; FARNELL 9731156
JP36: LED Ext. 5V; SCREWTERMINAL-3.5MM-2
JP41, JP45: M04PTH; 1X04
JP42: M15; 1X15
JP47: PIR; MOLEX-1X3; FARNELL 9731156
JP48: Light Sensor (e.g. TEMP6000); MOLEX-1X3; FARNELL 9731156
JP49: Temperature; MOLEX-1X3; FARNELL 9731156
JP201, JP202, JP203, JP301, JP302, JP303, JP401, JP402, JP403, JP501: M02POLAR; MOLEX-1X2
JP502: M023.5MM; SCREWTERMINAL-3.5MM-2
LOGO1: OSHW-LOGOM; OSHW-LOGO-M
Q2, Q3, Q4, Q5: FDD8451; DPAK
R1, R5, R6, R7, R8, R9, R10, R13, R20: 1k; 0805
R2: 330R; 0805
R3, R4, R11, R12, R17, R18, R202, R302, R402, R502: 10k; 0805
R14: 0.1; 2512; FARNELL 1435947
R15, R16, R19: 4k7; 0805
R201, R301, R401, R501: 10R; 0805
U1: PHOTON_WITH_STACKABLE_HEADERS; PHOTON_STACKABLE
U2: DS1820SOIC; DS18B20_SOIC
U3: 74AHC1G125; SOT23-5
U4: INA219AIDCNRSOIC; SO08
X2: PN87520-S

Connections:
3.3V: C5.2, C6.2, JP2.2, JP32.1, JP32.2, JP32.3, JP32.4, JP32.5, JP32.6, JP32.7, JP32.8, JP32.9, JP32.10, JP32.11, JP32.12, JP32.13, JP32.14, JP32.15, JP32.16, JP32.17, JP32.18, JP32.19, JP48.3, JP49.3, R3.2, R4.2, R15.1, R16.1, R19.1, U1.24 (3V3), U1.#24 (3V3), U1.@24 (3V3), U2.VCC, U4.5 (VS)
5V: C2.2, C3.2, C7.2, IC1.3 (VO), IC2.7 (IN), JP42.1, JP42.2, JP42.3, JP42.4, JP42.5, JP42.6, JP42.7, JP42.8, JP42.9, JP42.10, JP42.11, JP42.12, JP42.13, JP42.14, JP42.15, JP47.3, R13.2, R17.2, R20.1, U1.1 (VIN), U1.#1 (VIN), U1.@1 (VIN)
12V: C1.1 (+), IC1.1 (VI), JP45.1, JP45.2, JP45.3, JP45.4, JP201.2, JP202.2, JP203.2, JP301.2, JP302.2, JP303.2, JP401.2, JP402.2, JP403.2, JP501.2, JP502.1, R6.1, R7.1, R8.1, R9.1, R14.2, U4.7 (VIN-)
BUTTON: JP34.2, U1.19 (D6), U1.#19 (D6), U1.@19 (D6)
BUTTON_LED: R1.1, U1.20 (D7), U1.#20 (D7), U1.@20 (D7)
CHANNEL1: R201.2, U1.8 (A4), U1.#8 (A4), U1.@8 (A4)
CHANNEL2: R301.1, U1.7 (A5), U1.#7 (A5), U1.@7 (A5)
CHANNEL3: R401.1, U1.4 (RX), U1.#4 (RX), U1.@4 (RX)
CHANNEL4: R501.1, U1.3 (TX), U1.#3 (TX), U1.@3 (TX)
CHANNEL_1_SWITCHED: D1.C, JP201.1, JP202.1, JP203.1, Q2.4 (D)
CHANNEL_2_SWITCHED: D2.C, JP301.1, JP302.1, JP303.1, Q3.4 (D)
CHANNEL_3_SWITCHED: D3.C, JP401.1, JP402.1, JP403.1, Q4.4 (D)
CHANNEL_4_SWITCHED: D4.C, JP501.1, JP502.2, Q5.4 (D)
D3: U1.16 (D3), U1.#16 (D3), U1.@16 (D3)
DAC: U1.6 (DAC), U1.#6 (DAC), U1.@6 (DAC)
GND: C1.2 (-), C2.1, C3.1, C4.-, C5.1, C6.1, C7.1, D5.C, D6.C, D7.C, D9.C, IC1.2 (GND), IC2.6 (GND), JP1.2, JP2.1, JP33.1, JP33.2, JP33.3, JP33.4, JP33.5, JP33.6, JP33.7, JP33.8, JP33.9, JP33.10, JP33.11, JP33.12, JP33.13, JP33.14, JP33.15, JP33.16, JP33.17, JP34.1, JP35.1, JP36.2, JP41.1, JP41.2, JP41.3, JP41.4, JP47.1, JP48.1, JP49.1, Q2.3 (S), Q3.3 (S), Q4.3 (S), Q5.3 (S), R12.2, R18.1, R202.2, R302.2, R402.2, R502.2, U1.2 (GND), U1.21 (GND), U1.#2 (GND), U1.#21 (GND), U1.@2 (GND), U1.@21 (GND), U2.GND, U3.1 (/OE), U3.3 (GND), U4.1 (A1), U4.2 (A0), U4.6 (GND), X2.4, X2.S1, X2.S2
LIGHT_LEVEL: JP48.2, U1.11 (A1), U1.#11 (A1), U1.@11 (A1)
unnamed: D7.A, R5.1
unnamed: Q2.1 (G), R201.1, R202.1
unnamed: Q3.1 (G), R301.2, R302.1
unnamed: Q4.1 (G), R401.2, R402.1
unnamed: F1.2A, R5.2, R14.1, U4.8 (VIN+)
unnamed: R2.1, U3.4 (Y)
unnamed: Q5.1 (G), R501.2, R502.1
unnamed: JP35.2, R2.2
unnamed: D9.A, R20.2
unnamed: F1.1A, JP1.1
unnamed: JP34.3, R1.2
unnamed: D6.A, R13.1
unnamed: D5.A, R10.1
unnamed: D4.A, R9.2
unnamed: D3.A, R8.2
unnamed: JP47.2, R11.2
unnamed: D2.A, R7.2
unnamed: D1.A, R6.2
NEOPIXELS: U1.18 (D5), U1.#18 (D5), U1.@18 (D5), U3.2 (A)
PIR: R11.1, R12.1, U1.12 (A0), U1.#12 (A0), U1.@12 (A0)
RST: U1.23 (!RST), U1.#23 (!RST), U1.@23 (!RST)
SCL: JP2.3, R16.2, U1.14 (D1), U1.#14 (D1), U1.@14 (D1), U4.4 (SCL)
SDA: JP2.4, R19.2, U1.13 (D0), U1.#13 (D0), U1.@13 (D0), U4.3 (SDA)
TEMPERATURE: JP49.2, R15.2, U1.10 (A2), U1.#10 (A2), U1.@10 (A2), U2.DQ
USB_VA: IC2.8 (OUTA), X2.1
USB_VB: D8.A, IC2.5 (OUTB)
USB_VENABLE_A: IC2.1 (!ENA), R3.1, U1.17 (D4), U1.#17 (D4), U1.@17 (D4)
USB_VENABLE_B: IC2.4 (!ENB), R4.1, U1.15 (D2), U1.#15 (D2), U1.@15 (D2)
VBAT: U1.22 (VBAT), U1.#22 (VBAT), U1.@22 (VBAT)
VIN: C4.+, D8.C, JP35.3, JP36.1, R10.2, U3.5 (VCC)
VIN_MONITOR: R17.1, R18.2, U1.9 (A3), U1.#9 (A3), U1.@9 (A3)
WKP: U1.5 (WKP), U1.#5 (WKP), U1.@5 (WKP)

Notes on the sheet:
Channel 1: Controls upto 6 lights. PWM able
Channel 2: Controls upto 6 lights. PWM able
Check polarity of lights before fitting.
S.Harrison
2.04
Enable USB_VB to use internal 5V supply to power NeoPixels.
Use only for low number of Neopixels. Fit regulator with heatsink as needed.
Neopixel level shifter. 3v3 -> 5V
A3 / DAC not 5v Tol.
PWM on D0,D1,D2,D3, A4, A5, WKP, Rx,Tx
A5 & D2 Share PWM A4 & D3 Share PWM
5V PIR Sensor
12V Breakout
Monitor +5V (Photon VIn) Level. Tell if 3.7 LiPol or 5V
Optional: Leave R17/R18 empty for alternative A3 use
ALT when used with Particle Photon Battery Shield
5V PSU
Option: If using Particle Photon Battery Shield do not fit IC1. 5V rail comes from Photon VIn pin (3v7 - 5v range). Option: Replace IC1 with connector and use alternative 5V supply or LiPol battery.
DC input and current monitor.
12V DC Input
Max fuse 5A
Power
Lighting
CPU / Sensors
Breakout
On-board SOIC-8 sensor to monitor board temp.
External Sensor(s)
1 Wire DB18B20+ Temperature Sensors
Button with LED.
External I2C sensors
Used by Battery Shield. If used externally add 4k7 pull-ups
Can also be used as D0/D1
External light sensor
Photon
Neopixel Driver
Uses VIN to drive NeoPixels which may be connected to 5V rail.
Alternativly VIN may be supplied through screw terminal for higher current
When running on internal and Photon Battery Shield VIN is Max 3v7 on Battery, 5V on 12V supply
Max 500mA on internal power. Each R|G|B LED = 18mA. R+G+B = 54mA (@100%) * Max 10 White 100% LEDs. * Max 30 R|G|B @100%
NeoPixel Supply.

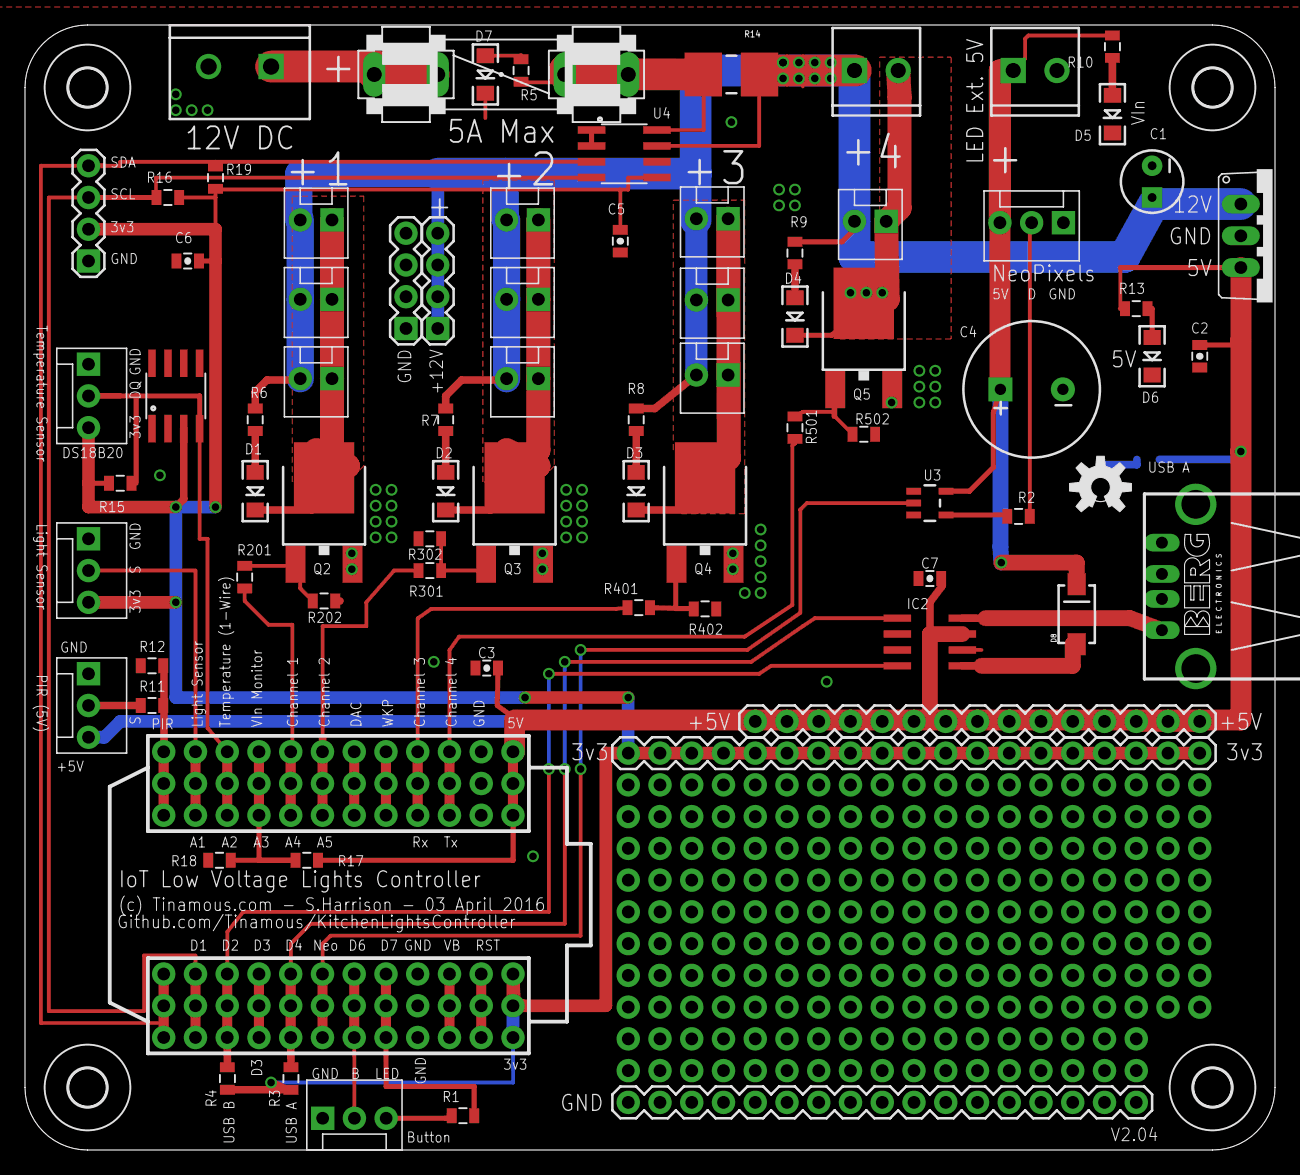
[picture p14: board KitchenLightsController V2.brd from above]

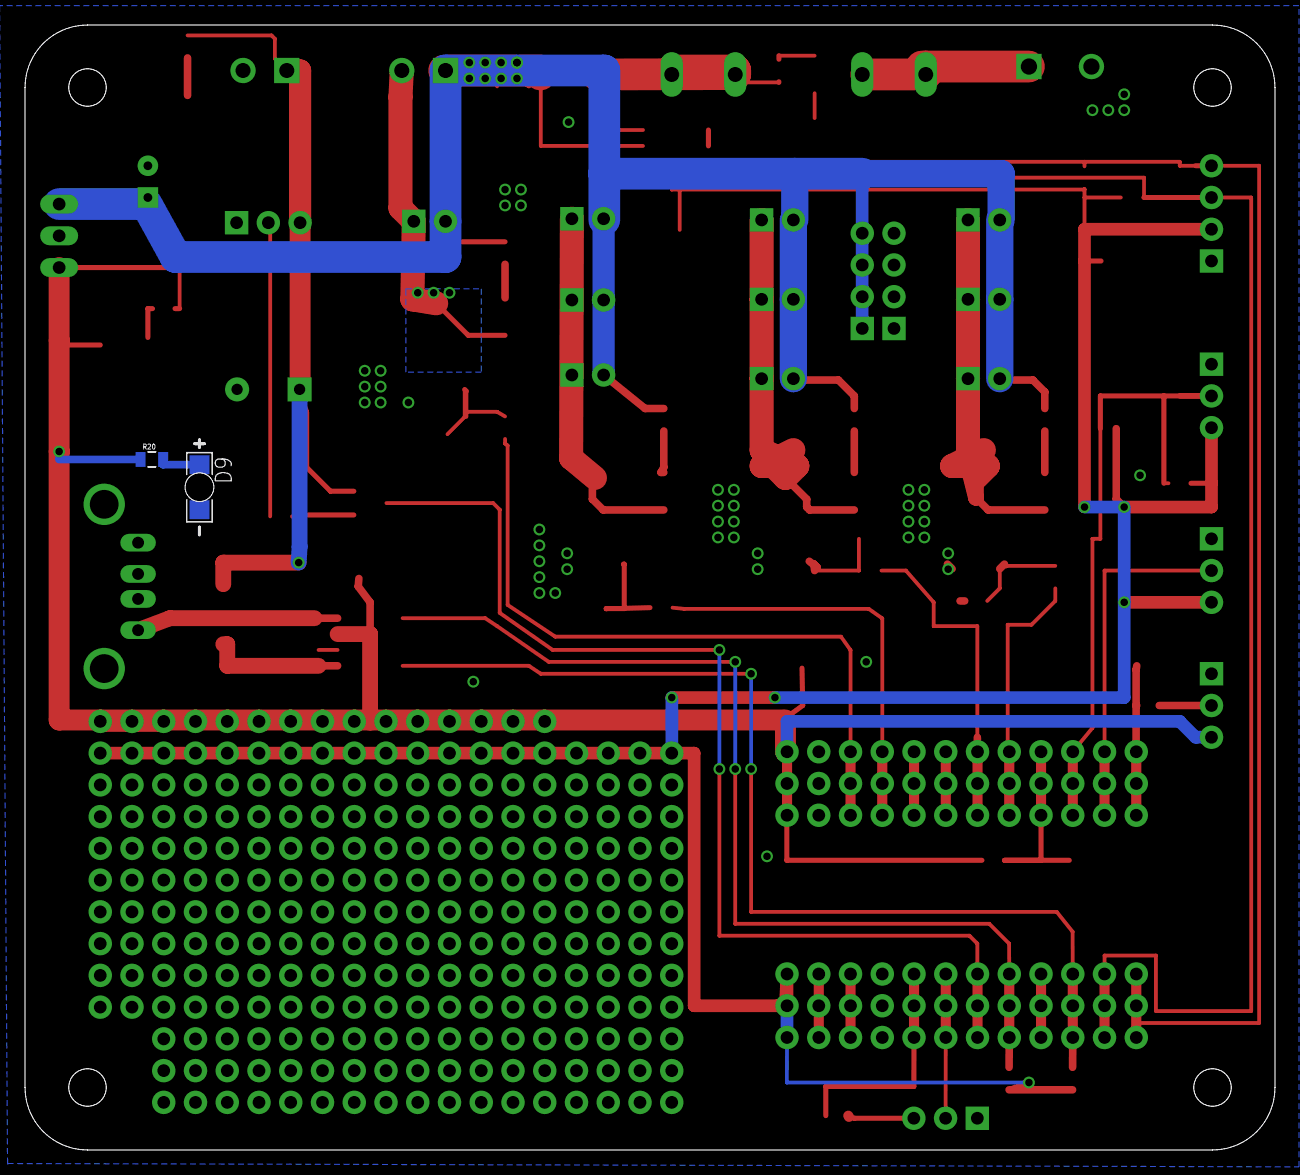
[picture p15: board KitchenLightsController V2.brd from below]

Board: 2 copper layers, 100.0 x 90.0 mm, 105 parts (2 on the bottom side), 49 nets.

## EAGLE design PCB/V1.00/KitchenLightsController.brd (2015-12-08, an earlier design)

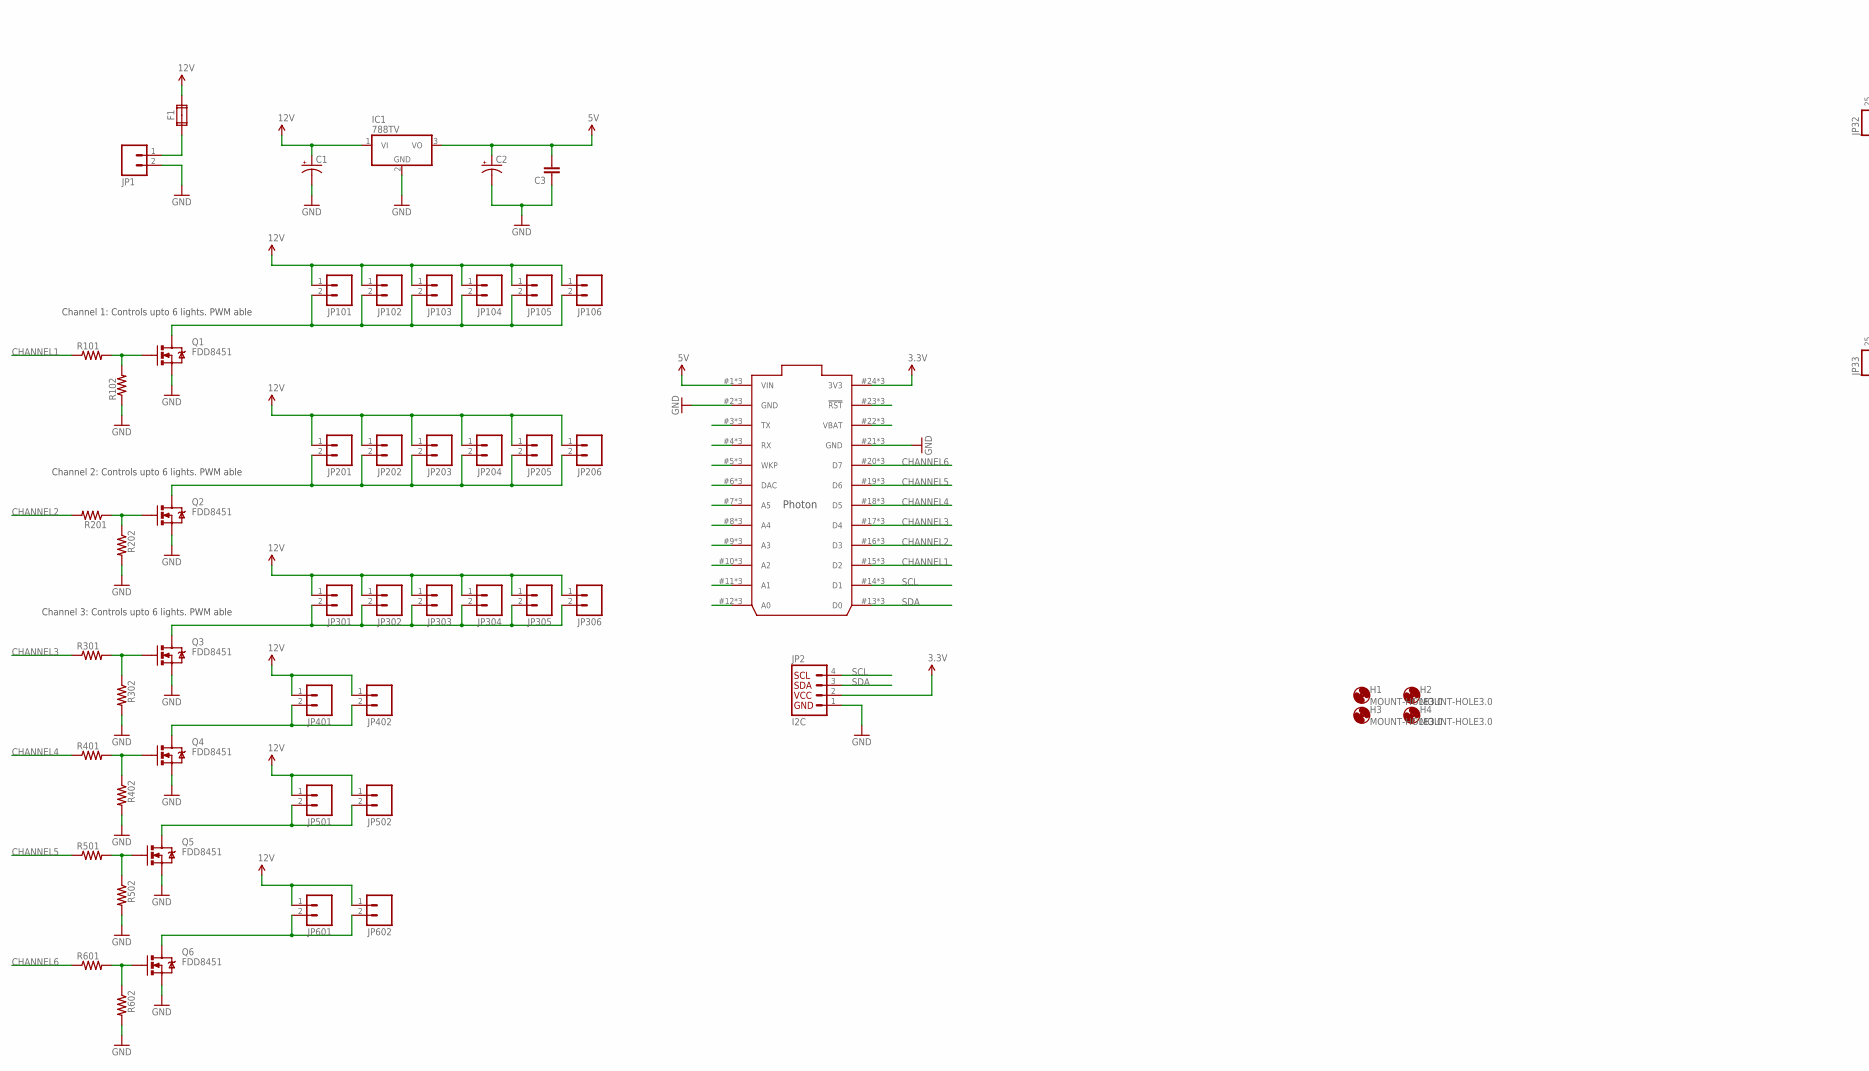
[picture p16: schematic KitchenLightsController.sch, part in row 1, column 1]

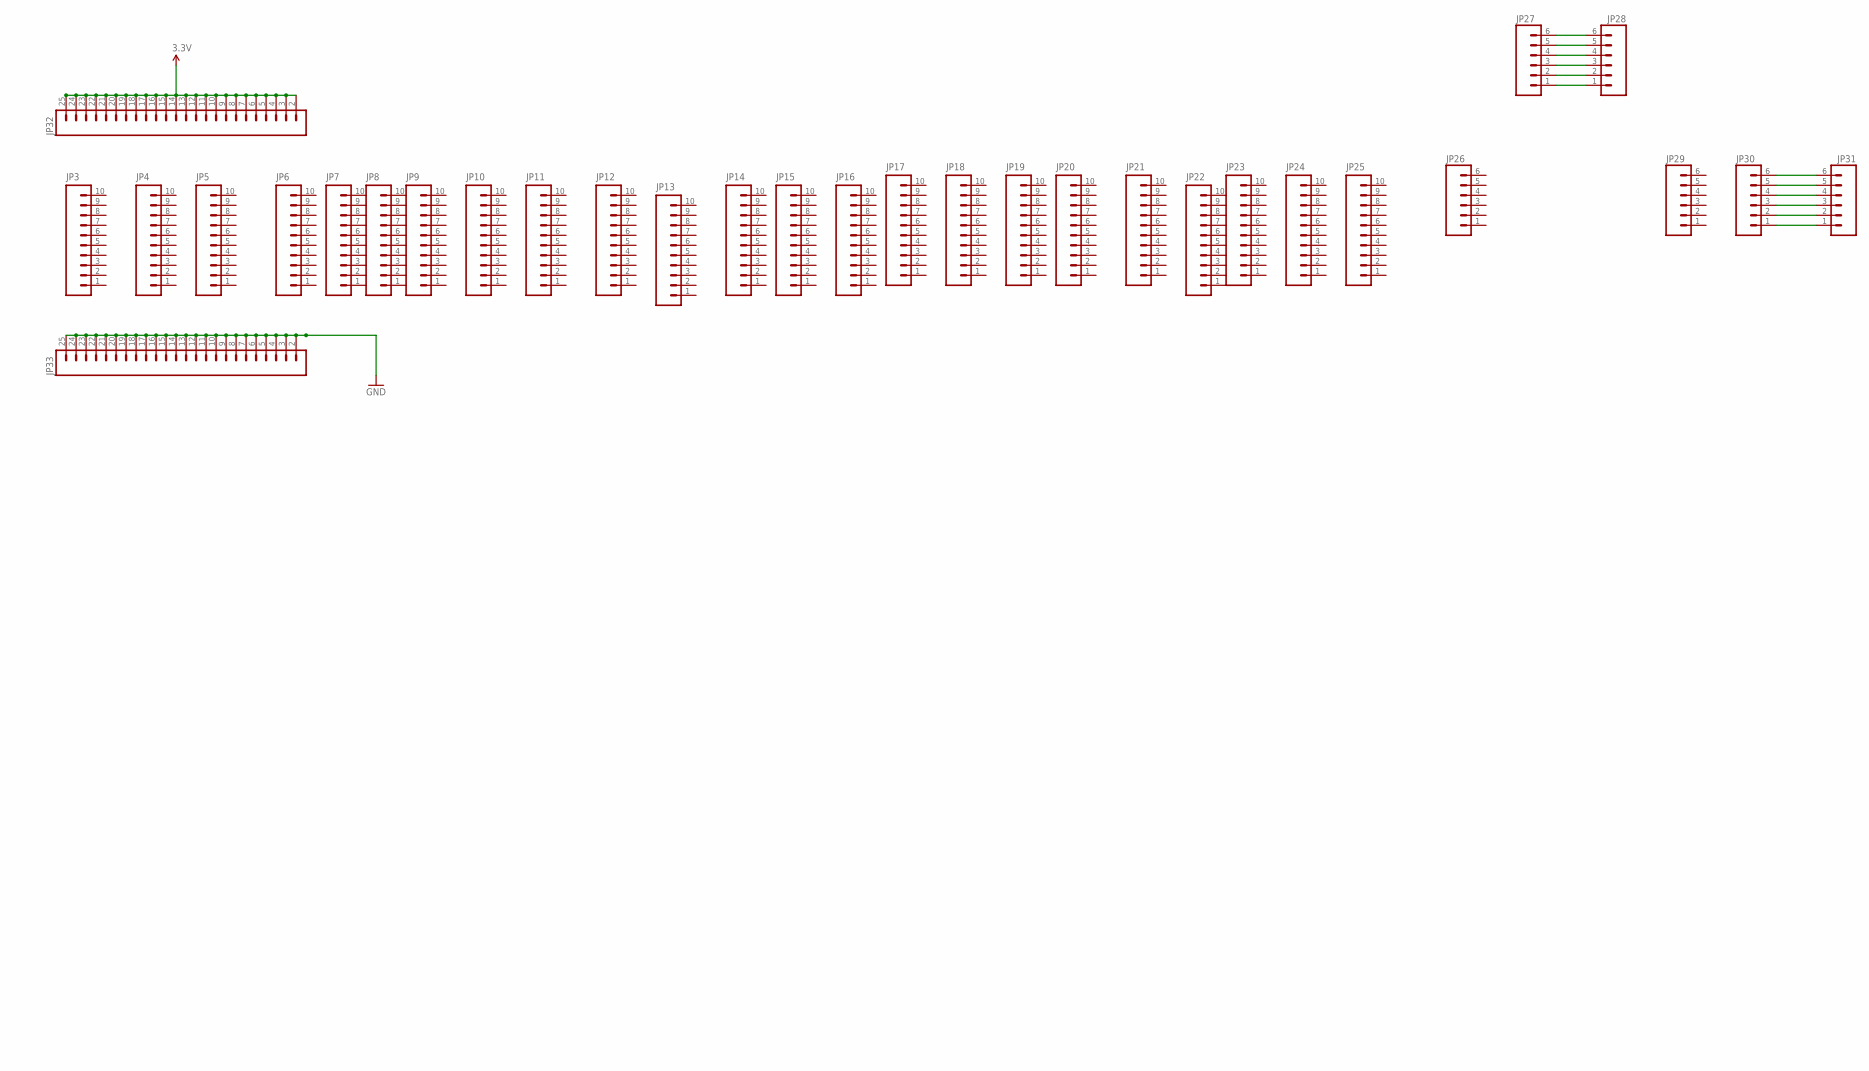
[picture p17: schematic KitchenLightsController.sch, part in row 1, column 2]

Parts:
C1, C2: 10UF-25V-20%(PTH); CPOL-RADIAL-10UF-25V
C3: 1UF-25V-10%(0805)"; 0805-CAP
F1: FUSE2P; FUSE1
H1, H2, H3, H4: MOUNT-HOLE3.0; 3,0
IC1: 788TV; TO220V
JP1, JP402, JP502, JP602: M023.5MM; SCREWTERMINAL-3.5MM-2
JP2: I2C; 1X04
JP3, JP4, JP5, JP6, JP7, JP8, JP9, JP10, JP11, JP12, JP13, JP14, JP15, JP16, JP17, JP18, JP19, JP20, JP21, JP22, JP23, JP24, JP25: M10NO_SILK_PTH_FEMALE; 1X10_NO_SILK
JP26, JP27, JP28, JP29, JP30, JP31: M06NO_SILK_FEMALE_PTH; 1X06_NO_SILK
JP32, JP33: M24; 1X24
JP101, JP102, JP103, JP104, JP105, JP106, JP201, JP202, JP203, JP204, JP205, JP206, JP301, JP302, JP303, JP304, JP305, JP306, JP401, JP501, JP601: M02POLAR; MOLEX-1X2
Q1, Q2, Q3, Q4, Q5, Q6: FDD8451; DPAK
R101, R102, R201, R202, R301, R302, R401, R402, R501, R502, R601, R602: RESISTOR0805-RES; 0805
U$1: PHOTON_WITH_STACKABLE_HEADERS; PHOTON_STACKABLE

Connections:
3.3V: JP2.2, JP32.2, JP32.3, JP32.4, JP32.5, JP32.6, JP32.7, JP32.8, JP32.9, JP32.10, JP32.11, JP32.12, JP32.13, JP32.14, JP32.15, JP32.16, JP32.17, JP32.18, JP32.19, JP32.20, JP32.21, JP32.22, JP32.23, JP32.24, JP32.25, U$1.24 (3V3), U$1.#24 (3V3), U$1.@24 (3V3)
5V: C2.1 (+), C3.2, IC1.3 (VO), U$1.1 (VIN), U$1.#1 (VIN), U$1.@1 (VIN)
12V: C1.1 (+), F1.2A, IC1.1 (VI), JP101.1, JP102.1, JP103.1, JP104.1, JP105.1, JP106.1, JP201.1, JP202.1, JP203.1, JP204.1, JP205.1, JP206.1, JP301.1, JP302.1, JP303.1, JP304.1, JP305.1, JP306.1, JP401.1, JP402.1, JP501.1, JP502.1, JP601.1, JP602.1
CHANNEL1: R101.1, U$1.15 (D2), U$1.#15 (D2), U$1.@15 (D2)
CHANNEL2: R201.2, U$1.16 (D3), U$1.#16 (D3), U$1.@16 (D3)
CHANNEL3: R301.1, U$1.17 (D4), U$1.#17 (D4), U$1.@17 (D4)
CHANNEL4: R401.1, U$1.18 (D5), U$1.#18 (D5), U$1.@18 (D5)
CHANNEL5: R501.1, U$1.19 (D6), U$1.#19 (D6), U$1.@19 (D6)
CHANNEL6: R601.1, U$1.20 (D7), U$1.#20 (D7), U$1.@20 (D7)
GND: C1.2 (-), C2.2 (-), C3.1, IC1.2 (GND), JP1.2, JP2.1, JP33.2, JP33.3, JP33.4, JP33.5, JP33.6, JP33.7, JP33.8, JP33.9, JP33.10, JP33.11, JP33.12, JP33.13, JP33.14, JP33.15, JP33.16, JP33.17, JP33.18, JP33.19, JP33.20, JP33.21, JP33.22, JP33.23, JP33.24, JP33.25, Q1.3 (S), Q2.3 (S), Q3.3 (S), Q4.3 (S), Q5.3 (S), Q6.3 (S), R102.1, R202.2, R302.2, R402.2, R502.2, R602.2, U$1.2 (GND), U$1.21 (GND), U$1.#2 (GND), U$1.#21 (GND), U$1.@2 (GND), U$1.@21 (GND)
unnamed: Q1.1 (G), R101.2, R102.2
unnamed: Q2.1 (G), R201.1, R202.1
unnamed: Q3.1 (G), R301.2, R302.1
unnamed: Q4.1 (G), R401.2, R402.1
unnamed: U$1.23 (!RST), U$1.#23 (!RST), U$1.@23 (!RST)
unnamed: U$1.22 (VBAT), U$1.#22 (VBAT), U$1.@22 (VBAT)
unnamed: Q5.1 (G), R501.2, R502.1
unnamed: Q6.1 (G), R601.2, R602.1
unnamed: JP201.2, JP202.2, JP203.2, JP204.2, JP205.2, JP206.2, Q2.4 (D)
unnamed: JP101.2, JP102.2, JP103.2, JP104.2, JP105.2, JP106.2, Q1.4 (D)
unnamed: F1.1A, JP1.1
unnamed: JP27.1, JP28.1
unnamed: U$1.12 (A0), U$1.#12 (A0), U$1.@12 (A0)
unnamed: U$1.11 (A1), U$1.#11 (A1), U$1.@11 (A1)
unnamed: U$1.10 (A2), U$1.#10 (A2), U$1.@10 (A2)
unnamed: U$1.9 (A3), U$1.#9 (A3), U$1.@9 (A3)
unnamed: U$1.8 (A4), U$1.#8 (A4), U$1.@8 (A4)
unnamed: U$1.7 (A5), U$1.#7 (A5), U$1.@7 (A5)
unnamed: U$1.6 (DAC), U$1.#6 (DAC), U$1.@6 (DAC)
unnamed: U$1.5 (WKP), U$1.#5 (WKP), U$1.@5 (WKP)
unnamed: U$1.4 (RX), U$1.#4 (RX), U$1.@4 (RX)
unnamed: U$1.3 (TX), U$1.#3 (TX), U$1.@3 (TX)
unnamed: JP27.2, JP28.2
unnamed: JP27.3, JP28.3
unnamed: JP27.4, JP28.4
unnamed: JP301.2, JP302.2, JP303.2, JP304.2, JP305.2, JP306.2, Q3.4 (D)
unnamed: JP27.5, JP28.5
unnamed: JP401.2, JP402.2, Q4.4 (D)
unnamed: JP501.2, JP502.2, Q5.4 (D)
unnamed: JP601.2, JP602.2, Q6.4 (D)
unnamed: JP27.6, JP28.6
unnamed: JP30.1, JP31.1
unnamed: JP30.2, JP31.2
unnamed: JP30.3, JP31.3
unnamed: JP30.4, JP31.4
unnamed: JP30.5, JP31.5
unnamed: JP30.6, JP31.6
SCL: JP2.4, U$1.14 (D1), U$1.#14 (D1), U$1.@14 (D1)
SDA: JP2.3, U$1.13 (D0), U$1.#13 (D0), U$1.@13 (D0)

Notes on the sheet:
Channel 1: Controls upto 6 lights. PWM able
Channel 2: Controls upto 6 lights. PWM able
Channel 3: Controls upto 6 lights. PWM able

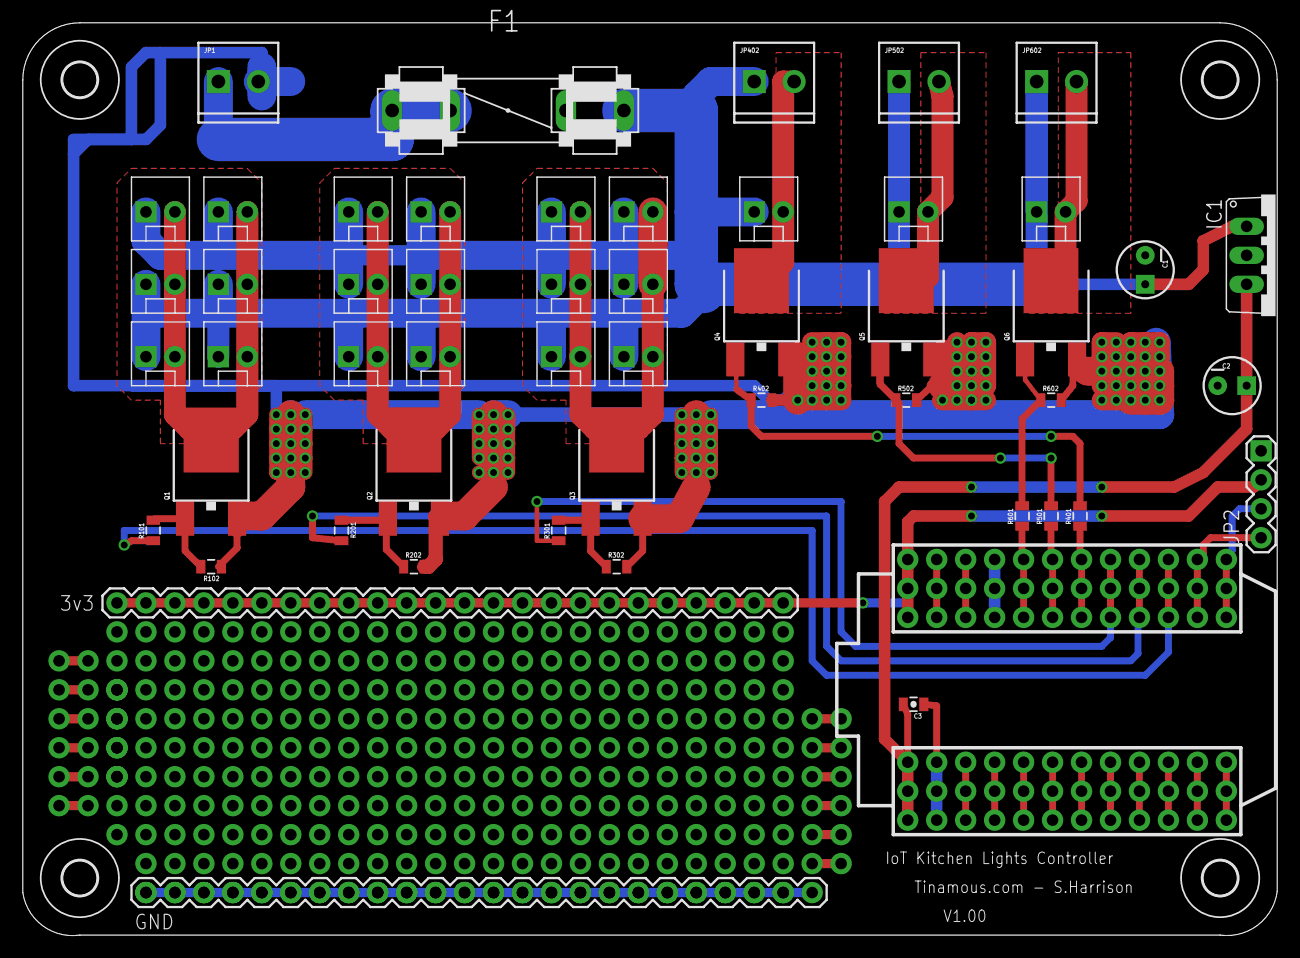
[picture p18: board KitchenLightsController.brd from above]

Board: 2 copper layers, 110.0 x 80.0 mm, 85 parts (0 on the bottom side), 49 nets.

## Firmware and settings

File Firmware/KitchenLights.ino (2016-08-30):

// This #include statement was automatically added by the Particle IDE.
#include "adafruit-ina219/adafruit-ina219.h"

// This #include statement was automatically added by the Particle IDE.
#include "neopixel/neopixel.h"

// This #include statement was automatically added by the Particle IDE.
#include "OneWire/OneWire.h"

// Configurations:
// Kitchen Sink:
// Channel 1: Under Cabinet Lights
// Channel 2: Over Cabinet
// Channel 3: Sink
// Channel 4: UV

//////////////////////////////////////////////////////////////////////////
// V2.02  board
//////////////////////////////////////////////////////////////////////////
int BoardVersion = 3;

// D0/D1 - I2C only
// D2 & D3 only pins with PWM support.
// A4 = Channel 1 (Under Cambinet Lights)
// A5 = Channel 2 (White LED Strips)
// RX = Channel 3 (Install specific - Skin strips, Microwave LED strip etc)
// TX = Channel 4 (UV)
int lamps[] = { A4, A5, RX, TX };
int maxLamps = 4;

// User panel switch
// Switch input
int switchPin = D6;
// Switch LED.
int switchLed = D7;

//int currentSensorPin = WKP;

int vInPin = A3;
OneWire ds = OneWire(A2);  // 1-wire signal on pin D4
int lightLevelPin = A1;
int pirPin = A0;



//byte sensor1[] = {0x28, 0xD6, 0xA9, 0x4E, 0x07, 0x00, 0x00, 0x27};
// onboard temperature sensor address.
byte sensor[8];

Adafruit_INA219 ina219;

//////////////////////////////////////////////////////////////////////////

int on(String command);
int dim(String command);
int off(String command);
int neoPixelsOn(String args);

int lamp = 0;

// State:
// 0: Off
// 1: Dim
// 2: Bright
int desiredState = 1; // power up dimmed.
int currentState = -1;

volatile bool buttonPressed = false;
volatile bool pirTriggered = false;

// IMPORTANT: Set pixel COUNT, PIN and TYPE
#define PIXEL_COUNT 4
#define PIXEL_TYPE WS2812B
#define PIXEL_PIN D5

Adafruit_NeoPixel strip = Adafruit_NeoPixel(PIXEL_COUNT, PIXEL_PIN, PIXEL_TYPE);

// Monitoring variables
float temperatureCelsius = 0;
double currentMilliAmps = 0;
double voltsIn = 0; // 5V rail monitor.
double supplyVoltage = 0; // the 12V in (monitored via current sensor)

// How many seconds to wait before turning off the lights.
double lightsOffInSeconds = 60;

// Measurement timer. Every n seconds.
//Timer takeMeasurementsTimer(10000, takeMeasurements);

//Timer dimLightsTimer(1000, dimLightsCheck);

void setup() {
    
    // Do not set A0 to analog in as it's not 5v tollerant in analog node.
    pinMode(A0, OUTPUT);
    
    for (int i=0; i< maxLamps; i++) {
        pinMode(lamps[i], OUTPUT);
        digitalWrite(lamps[i], false);
    }
    
    Particle.function("on", on);
    Particle.function("dim", dim);
    Particle.function("off", off);
    Particle.function("neoPixelsOn",neoPixelsOn);
    
    // Initialize the INA219.
    // By default the initialization will use the largest range (32V, 2A).  However
    // you can call a setCalibration function to change this range (see comments).
    ina219.begin();
    
    //pinMode(currentSensorPin, INPUT);
    pinMode(vInPin, INPUT);
    pinMode(lightLevelPin, INPUT);
    pinMode(pirPin, INPUT);
    pinMode(switchPin, INPUT_PULLUP);
    pinMode(switchLed, OUTPUT);
    digitalWrite(switchLed, false);
    
    // interrupt on the falling edge of A7 (switch pulled low)
    attachInterrupt(switchPin, buttonPressedIsr, FALLING);
    
    // TOOD: attachInterrup to PIR pin
    attachInterrupt(pirPin, pirTriggeredIsr, RISING);

    Particle.publish("Status", "Kitchen Lights Conroller. Version: 0.3.3, Board Version: " + String(BoardVersion));
    Particle.publish("Version", "0.3.3");
    
    // Setup NeoPixel LED (strip).
    strip.begin();
    strip.show(); // Initialize all pixels to 'off'
    
    if (BoardVersion>=2) {
        listTemperatureSensors();
    }
    
    //takeMeasurementsTimer.start();
    //dimLightsTimer.start();
}

int loopCounter = 0;

void loop() {
    
    // Enable the switch LED now set-up is complete.
    digitalWrite(switchLed, true);
    delay(50);
    
    // Turn the switch LED off whilst processing.
    // So if loop failes to be re-called the LED will be left off
    // indicating a problem.
    digitalWrite(switchLed, false);
    
    loopCounter++;
    if (loopCounter > 1200) {
        loopCounter = 0;
        takeMeasurements();
    }
    
    dimLightsCheck();

    // Handle button press.
    if (buttonPressed) {
        desiredState = currentState + 1;
        if (desiredState > 2) {
            desiredState = 0;
        }
        
        // force a debounce delay then clear the indicator.
        delay(300);
        
        // Default, switch lights off 10 minutes after user switched on.
        if (lightsOffInSeconds<600) {
            lightsOffInSeconds = 600; 
        }
        
        Particle.publish("Status", "Button pressed.", 60, PRIVATE);
        buttonPressed = false;
    }
    
    if (pirTriggered) {
        // PIR means movement detected so don't turn off the lights!
        // TODO: start timer to switch off the lights if no further PIR
        // and the user button not pressed.
        setDesiredState(currentState + 1);
        
        // force a debounce delay then clear the indicator.
        delay(500);
        
        // Default, switch lights off  2 minutes after user switched on.
        if (lightsOffInSeconds<60) {
            lightsOffInSeconds = 60; 
        }
        
        Particle.publish("Status", "PIR sensor triggered.", 60, PRIVATE);
        pirTriggered = false;
    }
    
    setState();
}

// *******************************************************
// State management for lights.
// *******************************************************
void setDesiredState(int state) {
    desiredState = state;
    if (desiredState > 2) {
        desiredState = 2;
    }
    
    if (desiredState < 0) {
        desiredState = 0;
    }
}

void setState() {
    if (currentState != desiredState) {
        
        switch (desiredState) {
            case 0:
                off("");
                break;
            case 1:
                dim("");
                break;
            case 2:
                on("");
                break;
        }
        
        currentState = desiredState;
    }
}

// Timer routine to check and see if it's time to dim the lights.
// Called every second by the timer and checks to see if it 
// is time for the lights to be dimmed.
void dimLightsCheck() {
    lightsOffInSeconds-=0.05;
    if (lightsOffInSeconds <= 0) {
        dimLightsOnTimer();
        lightsOffInSeconds = 0;
    }    
}

void dimLightsOnTimer() {
    // ignore if the lights are currently off.
    if (currentState == 0) {
        return;
    }
    
    // Dim the lights one stage before actually turning off.
    setDesiredState(currentState-1);
    
    Particle.publish("Status", "Lights off timeout. Requesting state: " + String(currentState-1), 60, PRIVATE);
    
    // Allow 60 seconds between states 
    // Full -- initial timeout/no activity -> dim -> 60s timeout -> off)
    // dim -- initial timeout/no activity -> off)
    lightsOffInSeconds = 60;
}

// *******************************************************
// Take temperature, current and Photon VIn (5v rail) measurements.
// Called by timer every n seconds.
// *******************************************************
void takeMeasurements() {
    if (BoardVersion >= 2) {
        // Read the temperature.
        // Show the temperature from the first sensor.
        showTemperature(sensor);
        showCurrent();
        readVin();
        
        Particle.publish("senml", "{e:[{'n':'boardTemperature','v':'" + String(temperatureCelsius) + "'},{'n':'current','v':'" + String(currentMilliAmps) + "'},{'n':'supplyVoltage','v':'" + String(supplyVoltage) + "'},{'n':'lightState','v':'" + String(currentState) + "'},{'n':'vin','v':'" + String(voltsIn) + "'}]}", 60, PRIVATE);
    }
}

void showCurrent () {
  float busvoltage = 0;
  float current_mA = 0;
  float loadvoltage = 0;

  float shuntvoltagemV = ina219.getShuntVoltage_mV();
  busvoltage = ina219.getBusVoltage_V(); // at VIN- pin.
  // Adafruit library assumes 0.1R. Kitchen lights are fitted with a 0R01 resistor.
  current_mA = (ina219.getCurrent_mA() * 10);
  loadvoltage = busvoltage + (shuntvoltagemV / 1000);
  
  currentMilliAmps = current_mA;
  supplyVoltage = loadvoltage;
  
  //Serial.print("Bus Voltage:   "); Serial.print(busvoltage); Serial.println(" V");
  //Serial.print("Shunt Voltage: "); Serial.print(shuntvoltagemV); Serial.println(" mV");
  //Serial.print("Load Voltage:  "); Serial.print(loadvoltage); Serial.println(" V");
  //Serial.print("Current:       "); Serial.print(current_mA); Serial.println(" mA");
  //Serial.println("");
}

void listTemperatureSensors() {
  //Serial.println("------------------------------------------");
  //Serial.println("Sensors Discovered:");
  
  int sensorNumber = 0;
    
  do {   
    byte addr[8];
    
    if ( !ds.search(addr)) {
      ds.reset_search();
      return;
    }
  
    //Serial.print("ROM =");
    byte i;
    for( i = 0; i < 8; i++) {
      //Serial.write(' ');
      //Serial.print(addr[i], HEX);
      sensor[i] = addr[i];
    }
  
    if (OneWire::crc8(addr, 7) != addr[7]) {
        Serial.println("CRC is not valid!");
        return;
    } 
    
    // the first ROM byte indicates which chip
    switch (addr[0]) {
      case 0x10:
        Particle.publish("Status", "Found  DS18S20 ");
        break;
      case 0x28:
        Particle.publish("Status", "Found  DS18B20 :-) ");
        break;
      case 0x22:
        Particle.publish("Status", "Found  DS1822");
        break;
      default:
        Particle.publish("Status", "Found non a DS18x20 family device ");
        return;
    } 
  } while (true);
}

void showTemperature(byte sensorAddress[]) {
    byte i;
    byte present = 0;
    byte data[12];

    //  showAddress(sensorAddress); 

    // Start conversion.  
    ds.reset();
    ds.select(sensorAddress);
    ds.write(0x44);

    delay(1000);   // Delay to ensure conversion has happened. This might be update 750ms for 12bit. 375 (11 bit), 187 (10bit), 93 (9 bit)

    // Read conversion
    present = ds.reset();
    ds.select(sensorAddress);    
    ds.write(0xBE);         // Read Scratchpad
  
      // Read data
    for ( i = 0; i < 9; i++) {           // we need 9 bytes
        data[i] = ds.read();
    }
    //showData( present, data);
  
    //Serial.print(" CRC=");
    //Serial.print(OneWire::crc8(data, 8), HEX);
    //Serial.println();
  
    temperatureCelsius = computeTemperature(data);
    
    //Particle.publish("Status", "Temperature read as " + String(temperatureCelsius));

    return;
}

float computeTemperature(byte data[]) {
  // Convert the data to actual temperature
  // because the result is a 16 bit signed integer, it should
  // be stored to an "int16_t" type, which is always 16 bits
  // even when compiled on a 32 bit processor.
  int16_t raw = (data[1] << 8) | data[0];

  byte cfg = (data[4] & 0x60);
  // at lower res, the low bits are undefined, so let's zero them
  if (cfg == 0x00) raw = raw & ~7;  // 9 bit resolution, 93.75 ms
  else if (cfg == 0x20) raw = raw & ~3; // 10 bit res, 187.5 ms
  else if (cfg == 0x40) raw = raw & ~1; // 11 bit res, 375 ms
  //// default is 12 bit resolution, 750 ms conversion time
    
  float celsius;
  celsius = (float)raw / 16.0;
  return celsius;
}

void readVin() {
    int vInAdc = analogRead(vInPin);
    // convert to ADC bits to millivolts
    // then x2 as it's a potential divider.
    voltsIn = (vInAdc * 0.8 * 2);
}

// *******************************************************
// Neopixel functions
// *******************************************************

void rainbow(uint8_t wait) {
  uint16_t i, j;

  for(j=0; j<256; j++) {
    for(i=0; i<strip.numPixels(); i++) {
    //for(i=0; i<4; i++) {
      strip.setPixelColor(i, Wheel((i+j) & 255));
    }
    strip.show();
    delay(wait);
  }
}

// Input a value 0 to 255 to get a color value.
// The colours are a transition r - g - b - back to r.
uint32_t Wheel(byte WheelPos) {
  if(WheelPos < 85) {
   return strip.Color(WheelPos * 3, 255 - WheelPos * 3, 0);
  } else if(WheelPos < 170) {
   WheelPos -= 85;
   return strip.Color(255 - WheelPos * 3, 0, WheelPos * 3);
  } else {
   WheelPos -= 170;
   return strip.Color(0, WheelPos * 3, 255 - WheelPos * 3);
  }
}

// *******************************************************
// Particle function functions (i.e. Internet exposed
// *******************************************************)

int on(String args) {
    
    if (args == "UNDER") {
        // Channel 1
        setLamp(0, true);
        Particle.publish("Status", "Under Lights On");
        return 0;
    } else if (args == "OVER") {
        // Channel 2
        setLamp(1, true);
        Particle.publish("Status", "Over Lights On");
        return 1;
    } else if (args == "SINK") {
        // Channel 3
        setLamp(2, true);
        Particle.publish("Status", "Sink Lights On");
        return 2;
    } else if (args == "UV") {
        // Channel 4
        setLamp(3, true);
        Particle.publish("Status", "UV Lights On");
        return 3;
  } else {
        // Generic "On" command.
        // Set Under, Over and sink to be on
        // UV to off.
        setLamp(0, true);
        setLamp(1, true);
        setLamp(2, true);
        setLamp(3, false);
        
        for(int pixel=0; pixel<strip.numPixels(); pixel++) {
            // Blue - 100%
            strip.setColorDimmed(pixel, 0, 0, 255, 255);
            //strip.setPixelColor(pixel, 0));
        }
        strip.show();
        
        Particle.publish("Status", "Lights On");
        
        return 200;
    }
}

int dim(String args) {
    if (args == "OVER") {
        setLamp(0, false);
        setLampDimmed(1, 40);
        setLamp(2, false);
        setLamp(3, false);
        Particle.publish("Status", "Over Lights Dimmed");
        return 1;
    } else {
        setLampDimmed(0, 40);
        setLampDimmed(1, 40);
        setLamp(2, false);
        setLamp(3, false);
        
        for(int pixel=0; pixel<strip.numPixels(); pixel++) {
            // Blue - 100%
            strip.setColorDimmed(pixel, 0, 255, 255, 128);
            //strip.setPixelColor(pixel, 0));
        }
        strip.show();
        
        Particle.publish("Status", "Lights Dimmed");
        return 2;
    }

    return 40;
}

int off(String args) {
    for (int i=0; i<maxLamps; i++) {
        setLamp(i, false);
    }
    
    for(int pixel=0; pixel<strip.numPixels(); pixel++) {
        strip.setColorDimmed(pixel, 0, 0, 0, 0);
        //strip.setPixelColor(pixel, 0));
    }
    strip.show();
    
    Particle.publish("Status", "All Lights Off");

    return 0;
}

int neoPixelsOn(String args) {
    rainbow(200);
    
    Particle.publish("Status", "Neopixel lights on");
    
    return 0;
}

// *******************************************************
// Helpers
// *******************************************************

void setLamp(int lamp, bool state) {
    digitalWrite(lamps[lamp], state);
}

void setLampDimmed(int lamp, int brightness) {
    analogWrite(lamps[lamp], brightness);
}

// *******************************************************
// Interrup service routines.
// *******************************************************
void buttonPressedIsr() {
    buttonPressed = true;
}

// ISR for PIR sensor.
void pirTriggeredIsr() {
    pirTriggered = true;
}

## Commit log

2015-12-08 Initial version - as sent to OSHPark.com
    [KitchenLightsController.brd, KitchenLightsController.sch]
2016-01-19 Added V2 PCB. * Added PIR input * Added Light level input * Added Temperature sensor and 1 Wire temperature input * Added Switch + LED Input * Added VIn level sense * Removed Original channels 1 & 6 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
    Sent to DirtyPCB's for fab.
    [KitchenLightsController V2.brd, KitchenLightsController V2.sch]
2016-02-05 Updated with minor tweaks and some additional component values specified from build of the v2.00 board.
    [KitchenLightsController V2.brd, KitchenLightsController V2.sch]
2016-04-03 Corrected Gnd/+5V labels on NeoPixel connector which were the wrong way around.
    Moved Via from area under Photon as it messed with the text.
    [KitchenLightsController V2.brd, KitchenLightsController V2.sch]
2016-04-03 Added assembly notes to readme file.
2016-04-03 Updated date on (c)
    [KitchenLightsController V2.brd]
2016-04-03 Added 3D printable box.
    [LightControllerBox.scad, LightControllerBox.stl, LightControllerBoxLid.stl]
2016-04-03 Moved + sign on NeoPixel input slightly to the left.
    [KitchenLightsController V2.brd]
2016-04-03 Added reverse mount LED for OSH Logo.
    Modified USB channel B output to drive NeoPixels rather than using the jumper, as NeoPixels have a 1mA per pixel base current consumption this allows a string or NeoPixels to be switched off to save power, as well as providing current limiting etc. as provided by the USB driver chip.
    [KitchenLightsController V2.brd, KitchenLightsController V2.sch]
2016-04-03 Made (hole for) switch optional.
    Improved lid.
    Reduced hole for power inlet
    [LightControllerBox-NoSwitch.stl, LightControllerBox.scad, LightControllerBoxLid.stl]
2016-04-05 Added gap between lid and base variable and reduced it to 0.3mm to provice a tighter fit.
    [LightControllerBox-NoSwitch.stl, LightControllerBox.scad, LightControllerBox.stl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]
2016-08-30 Adding initial version of the SmartThings device handler.
2016-08-30 Updated PCB pdfs

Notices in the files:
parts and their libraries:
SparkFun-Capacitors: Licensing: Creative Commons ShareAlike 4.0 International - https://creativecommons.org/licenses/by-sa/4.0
